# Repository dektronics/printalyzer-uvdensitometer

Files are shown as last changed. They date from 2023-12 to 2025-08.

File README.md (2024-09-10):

# Printalyzer UV/VIS Densitometer

Printalyzer Densitometer Logo

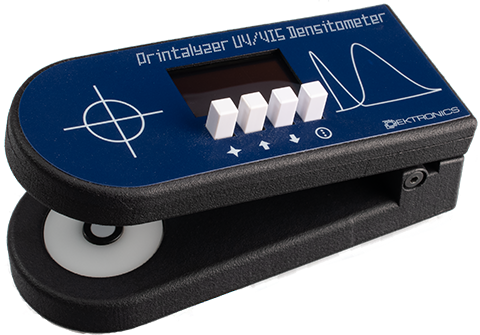
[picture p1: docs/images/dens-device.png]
Printalyzer Densitometer Device


## Introduction

The Printalyzer UV/VIS Densitometer is a project whose goal is the creation of an
affordable reflection and transmission densitometer for photographic darkroom
use.

It differs from the original B&W densitometer product in that it adds a UV
measurement channel for alternative processes needs.

This project will use the B&W [Printalyzer Densitometer](https://github.com/dektronics/printalyzer-densitometer) DPD-100 design as its basis, and will make all efforts to share the same mechanical design and components.

_**This project is currently very much in the R&D stage, and should not be considered complete or functional at this point. It may change substantially as initial prototypes are constructed and tested.**_

## Project Layout

### Hardware
The "hardware" directory contains [KiCad](https://www.kicad.org/) projects
with the complete circuit schematics, bill-of-materials, and
PCB layouts.

### Software
The "software" directory contains all the source code for the bootloader
and firmware that runs on the hardware.

The desktop software to interface with this densitometer from a computer is
maintained in a separate repository, as it contains support for multiple
densitometer devices.

### Enclosure
The "enclosure" directory contains any CAD models and related resources
necessary to physically assemble the device.

## License
Individual directories will contain LICENSE files as needed, with relevant
details. Generally, the hardware will be CC BY-SA and the software will be
BSD 3-Clause. However, external resources may have their own individual license terms.

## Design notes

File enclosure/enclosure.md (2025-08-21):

# Printalyzer UV/VIS Densitometer Enclosure

## Introduction

This directory contains all the assets necessary to produce the physical
enclosures for the Printalyzer Densitometer. This document explains what
component each file represents, and also provides a bill-of-materials
for additional hardware needed for assembly.

The actual assembly instructions are located elsewhere.

## 3D Models

Models designed for 3D printing are provided as both STL and 3MF files,
and are listed without their file extension.

Original CAD files are provided in the native format of the CAD application.

The models that make up the construction of the device must be printed
in a material that is minimally reflective and opaque to both visible and
infrared light.

_**Note: Many of the models for components beyond the main enclosure were
created by deriving from either the main assembly CAD project or related
projects that might include non-distributable models of 3rd party
components. As such, original CAD files may not be provided for everything
listed here.**_

These files are in the `models_3d` subdirectory.

### CAD Projects

* `dens-enclosure.f3z` - Main CAD model for the enclosure, designed in Fusion 360.  
  (_Note: Does not include models of the PCBs or mounting hardware, to avoid
  accidentally redistributing component models that are under restrictive
  license terms._)

### Main Enclosure Components

* `dens-main-housing` - Main housing for the circuit board and major components
* `dens-main-cover` - Top cover for the main housing
* `dens-main-cover-dev` - Alternative top cover with a clearance hole for a debug connector
* `dens-base` - Base housing that contains the transmission LED components
* `dens-base-cover` - Bottom cover for the base housing

### Internal Components

* `filter-stack-holder` - Tray that sits on top of the lens assembly and holds the sensor diffuser
* `filter-stack-lower-ring` - Lower ring that acts as a spacer, aperture, and helps to hold the sensor
  diffuser in place.
* `filter-stack-upper-ring` - Upper ring that sits between the filter stack and the main circuit
  board to act as a light seal. Should be made from an opaque flexible material, such as rubber or foam.
* `sensor-board-cover` - Internal cover for the backside of the circuit board above the sensor elements

### Assembly Jigs

* `jig-dens-main-assembly` - Jig to hold the main housing during assembly
* `jig-dens-base-assembly` - Jig to hold the base, upside down, during assembly
* `jig-display-mounting` - Jig to help align the PCB and OLED display for assembly
* `jig-overlay-mounting` - Jig to help align the main cover and graphic overlay for assembly
* `jig-spring-trimmer-base` - Base portion of a jig to help hold the torsion springs
  in place while trimming them with a rotary tool
* `jig-spring-trimmer-cover` - Cover portion of a jig to help hold the torsion springs
  in place while trimming them with a rotary tool
* `jig-upside-down` - Jig to hold the complete device in an upside-down orientation,
  which is useful for mating the top and bottom halves and for installing the base cover
* `jig-cal-strip-measure` - Jig for holding a calibration reference for measurement,
  when the label markings have not yet been applied

### Calibration Jigs

* `jig-cal-t2120-center` - Jig to repeatably position a Stouffer T2120 step wedge for linearity calibration (center position)
* `jig-cal-t2120-side` - Jig to repeatably position a Stouffer T2120 step wedge for linearity calibration (side position)
* `jig-cal-t5100-full` - Jig to repeatably position s Stouffer T5100 step wedge for measurement or target calibration (measurement spot at the patch center)
* `jig-cal-t5100-labeled` - Jig to repeatably position a Stouffer T5100 step wedge for measurement or target calibration (measurement spot shifted to accommodate a 4x1" label)

## 2D Models

Models designed for laser cutting are provided as DXF files.
They are provided in both single-part and multi-part grid versions.

These files are in the `models_2d` subdirectory.

* `stage-plate-ring.dxf` - The stage plate outer ring. Cut from a white acrylic
  material that is 1.5mm thick.
* `filter-stack-upper-ring.dxf` - Alternative version of the filter stack upper ring model
  from above, to be used if laser cutting from a stock material. Must use a clean, opaque,
  and flexible material that is 1.5mm thick.
* `sensor-board-cover.dxf` - Alternative version of the sensor board cover
  from above. Must be cut from a material that is opaque to visible and
  infrared light and that is approximately 1mm thick. If thicker, then the
  mounting screws in the sensor head area will need to be longer.

## Graphic Overlay

The graphic overlay is a piece of custom cut polycarbonate material
that has printing and a transparent window for the display.
For all device builds so far, it has been ordered from [JRPanel](https://www.jrpanel.com/).
These files are the design artifacts that have been used when placing
that order.

These files are in the `overlay` subdirectory.

* `graphic-overlay-dims.pdf` - CAD drawing showing all the relevant
  dimensions of the overlay
* `graphic-overlay.dxf` - 2D CAD file representing the relevant
  dimensions of the overlay
* `graphic-overlay.svg` - Inkscape design for the overlay, annotated as appropriate.
* `graphic-overlay.pdf` - PDF export of the design, for ease of exchange.

## Product Labels

* 2x1" label, Zebra Z-Xtreme 4000T High-Tack Silver, SKU: 10023174

## Additional Components

### Non-PCB Electronic Components

These are components that are not included in the PCB's bill-of-materials,
but are ordered from the same kinds of vendors and are necessary to assemble
a complete device.

* Button caps (x4)
  * **E-Switch 1SWHT**
  * Mouser PN: 612-1S-WHT
* 1.3" OLED Display Screen
  * **ER-OLED013A1-1W**
  * https://www.buydisplay.com/white-1-3-inch-oled-i2c-arduino-ssd1306-display-module-connector-fpc
* Cable to connect Transmission LED Board to Main Board
  * **JST JUMPER 04SR-3S - 04SR-3S 4"**
  * Manufacturer PN: A04SR04SR30K102A

### Non-Electronic Components

These components are not necessarily sourced from electronics vendors, but
are still necessary for the assembly of the device.

* Sensor head lens
  * Aspherical focusing acrylic plano-convex lens, 5mm diameter
  * Sourced from AliExpress
  * https://www.aliexpress.us/item/3256802937733209.html
* Sensor head aperture
  * M2 Hard Fiber Washer, 2.3mm inside diameter, 5mm outside diameter
  * McMaster-Carr PN: 95225A210
* Sensor head diffuser
  * UV Fused Silica diffuser, 10mm diameter, 1mm thick
  * Sourced from UQG Optics, part number **DUV-1010**
* Transmission light diffuser
  * White flashed opal, 6mm diameter, 2.5mm thick
  * Sourced from UQG Optics as a custom order
* Transmission light diffuser gasket
  * Square-Profile Oil-Resistant Buna-N O-Ring
  * 1.5mm wide, 6mm inside diameter
  * McMaster-Carr PN: 1171N142

## Assembly Hardware

* M2 x 4mm thread forming screws (x2)
  * McMaster-Carr PN: 90380A324
* M2 x 5mm thread forming screws (x2)
  * McMaster-Carr PN: 90380A325
* M2 x 6mm thread forming screws (x4)
  * McMaster-Carr PN: 90380A326
* M2 x 8mm thread forming screws (x4)
  * McMaster-Carr PN: 90380A328
* M2 x 8mm flat head black screws (x4)
  * McMaster-Carr PN: 91698A204
* M3 x 20mm low-profile socket head partially threaded screws (x2)
  * McMaster-Carr PN: 93070A076
* Torsion Spring, 180 deg Right-Hand wound
  * McMaster-Carr PN: 9271K97
  * Gardner Spring PN: GT2814018-MR
* Torsion Spring, 180 deg Left-Hand wound
  * McMaster-Carr PN: 9271K98
  * Gardner Spring PN: GT2814018-ML
* Flanged sleeve bearings for 3mm shaft, 5mm long (x2)
  * McMaster-Carr PN: 2705T112
  * Igus PN: JFM-0304-05
* Rubber bumbers (x4)
  * **3M BUMPER CYLIN 0.315" DIA BLACK**
  * Manufacturer PN: SJ5076
  * Digi-Key PN: 3M156065-ND
* Adhesive wheel weights, 1/4 oz (x6)
  * Available from a variety of vendors
* All-purpose adhesive
  * E6600 QuickHOLD
* UV-Curing adhesives
  * Norland Products NOA 68
  * Norland Products NOA 72
* Foam mounting tape (3/4"x 15ft)
  * **3M VHB 3/4-5-4991**
  * McMaster-Carr PN: 8127A88

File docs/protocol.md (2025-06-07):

USB Control Protocol
====================

The Printalyzer Densitometer presents itself to a host computer as a USB CDC
device, which is essentially a virtual serial port. Through this interface,
it is possible to configure and control all aspects of the device.
This document covers that protocol.

## Data Formats

All command and response lines are terminated by a CRLF (`\r\n`).

### Command Format

Each command is sent in a standardized form:

`<TYPE><CATEGORY> <ACTION>[,<ARGS>]`
* **TYPE** values:
  * `S` - Set (change a value or state)
  * `G` - Get (return a value or state)
  * `I` - Invoke (perform some action on the system)
* **CATEGORY** values:
  * `S` - System (top-level system commands)
  * `M` - Measurement (commands related to density measurements)
  * `C` - Calibration (commands related to device calibration)
  * `D` - Diagnostics (general diagnostic commands)
* **ACTION** values are specific to each category, and documented in the following sections
* **ARGS** values are specific to each action, and not all actions may have them

### Response Format

Command responses typically fit a format that is a mirror of the command that
triggered them, except the `[,<ARGS>]` field is changed to represent
information specific to that particular command response.

The common formats for these response arguments are:
* `OK` - The command completed successfully, with no further information
* `ERR` - The command failed
* `NAK` - The command was either unrecognized or can't be processed in the current system state
* `A,B,C,D` - A comma-separated list of elements
  * Strings in this list may be quoted
  * Floating point values are returned in a little-endian hex encoded format
* A multi-line response as follows:
  ```
  TC ACTION,[[\r\n
  Line 1
  Line 2
  ...
  ]]\r\n  
  ```

### Density Format

Density readings are sent out-of-band whenever a reading is taken on the device,
and are not sent in response to commands. They follow the format of:

`<R/T/U><+/->#.##D`

An example of a density reading would be something like `R+0.20D`, `T+2.85D`, or `U+1.90D`

### Logging Format

Redirected log messages have a unique prefix of `L/`, where "L" is the logging level.
By looking for this pattern, they can be filtered out from the rest of the command
protocol. By default, log messages are not redirected out the USB CDC interface.

Expected log levels include: `A`, `E`, `W`, `I`, `D`, and `V`

## Commands

Note: Commands that could conflict with the local device user interface
may require that the device first be placed into "remote control" mode.
If sent outside of this mode, they may fail with a **NAK**. Commands of
this type are marked below.

Commands that lack a documented response format will return either `OK` or `ERR`.

### System Commands

* `GS V` - Get project name and version
  * Response: `GS V,<Project name>,<Version>`
* `GS B` - Get firmware build information
  * Response: `GS B,<Build date>,<Build describe>,<Checksum>`
* `GS DEV`  - Get device information
  * Response: `GS DEV,<HAL Version>,<MCU Device ID>,<MCU Revision ID>,<SysClock Frequency>`
* `GS RTOS` - Get FreeRTOS information
  * Response: `GS RTOS,<FreeRTOS Version>,<Heap Free>,<Heap Watermark>,<Task Count>`
* `GS UID`  - Get device unique ID
  * Response: `GS UID,<UID>`
* `GS ISEN` - Internal sensor readings
  * Response: `GS ISEN,<VDDA>,<MCU_Temp>,<Sensor_Temp>`
  * Note: Response elements have unit suffixes appended, so it looks like "3300mV,24.5C,22.0C"
* `IS REMOTE,n` - Invoke remote control mode (enable = 1, disable = 0)
  * Response: `IS REMOTE,n`
* `SS DISP,"text"` - Write the provided text to the display ***(remote mode)***
  * Note: Line breaks are sent as the literal text "\n"
    and backslashes are sent as the literal text "\\".
    Double-quote characters inside the string are not supported. ***(remote mode)***
* `SS DISP, n` - Set the display to be enabled or disabled (enable = 1, disable = 0)

### Measurement Commands

* `GM REFL` - Get last VIS reflection measurement
  * Response: `GM REFL,<D>`
* `GM TRAN` - Get last VIS transmission measurement
  * Response: `GM TRAN,<D>`
* `GM UVTR` - Get last UV transmission measurement
  * Response: `GM TRAN,<D>`
* `SM FORMAT,x` - Change measurement output format
  * Possible measurement formats are:
    * `BASIC` - The default format, which just includes the measurement mode
      and density value in a human-readable form, to 2 decimal places
    * `EXT` - Appends the density, zero offset, and gain adjusted basic count
      readings in the hex encoded floating point format
  * Note: The active format will revert to **BASIC** upon disconnect
* `SM UNCAL,x` - Allow measurements without target calibration (0=false, 1=true)
  * Note: This setting will revert to false upon disconnect

### Calibration Commands

* `IC GAIN` - Invoke the sensor gain calibration process ***(remote mode)***
  * This is a long process in which the device must be held closed.
    It will automatically abort if the hinge detect switch is released
    during the process.
  * The result of this process will be updated measurement light and
    sensor gain calibration values.
  * While running, there will be a series of `STATUS` responses followed by
    a single `OK` or `ERR` response.
  * Status is reported via the following responses:
    * `IC GAIN,STATUS,n,m` where n is an enumerated value as follows:
      * 0 = initializing
      * 1 = finding gain measurement brightness (m = gain level)
      * 2 = waiting between measurements
      * 3 = measuring gain level (m = gain being measured)
      * 4 = calibration process failed
      * 5 = calibration process complete
    * `IC GAIN,OK` - Gain calibration process is complete
    * `IC GAIN,ERR` - Gain calibration process has failed
* `GC GAIN` - Get sensor gain calibration values
  * Response: `GC GAIN,<G0>,<G1>,<G2>,<G3>,<G4>,<G5>,<G6>,<G7>,<G8>,<G9>`
  * Note: `<G0..9>` represent gain values, doubling with each increment, from 0.5x to 256x
* `SC GAIN,<G0>,<G1>,<G2>,<G3>,<G4>,<G5>,<G6>,<G7>,<G8>,<G9>` - Set sensor gain calibration values
* `GC VTEMP` - Get VIS sensor temperature calibration values
  * Response: `GC VTEMP,<B0>,<B1>,<B2>`
* `SC VTEMP,<B0>,<B1>,<B2>` - Set VIS sensor temperature calibration values
  * _Note: There is no on-device way to perform temperature calibration.
    It is performed using an externally controlled process that captures
    device measurements while the device is inside a thermal test chamber,
    does a series of calculations, then provides a set of coefficients
    that are loaded onto the device using this command._
* `GC UTEMP` - Get UV sensor temperature calibration values
  * Response: `GC VTEMP,<B0>,<B1>,<B2>`
* `SC UTEMP,<B0>,<B1>,<B2>` - Set UV sensor temperature calibration values
* `GC REFL` - Get VIS reflection density calibration values
  * Response: `GC REFL,<LD>,<LREADING>,<HD>,<HREADING>`
* `SC REFL,<LD>,<LREADING>,<HD>,<HREADING>` - Set VIS reflection density calibration values
  * The reading values are assumed to be in gain adjusted basic counts
* `GC TRAN` - Get VIS transmission density calibration values
  * Response: `GC TRAN,<LD>,<LREADING>,<HD>,<HREADING>`
* `SC TRAN,<LD>,<LREADING>,<HD>,<HREADING>` - Get VIS transmission density calibration values
  * The reading values are assumed to be in gain adjusted basic counts
  * Note: `<HD>` is always zero, and only included here for the sake of consistency
* `GC UVTR` - Get UV transmission density calibration values
  * Response: `GC UVTR,<LD>,<LREADING>,<HD>,<HREADING>`
* `SC UVTR,<LD>,<LREADING>,<HD>,<HREADING>` - Get UV transmission density calibration values
  * The reading values are assumed to be in gain adjusted basic counts
  * Note: `<HD>` is always zero, and only included here for the sake of consistency

### Diagnostic Commands

* `GD DISP` - Get display screenshot
  * Response is XBM data in the multi-line format described above
* `GD LMAX` -> Get maximum light duty cycle value
* `SD LR,nnn` -> Set VIS reflection light duty cycle (nnn/LMAX) ***(remote mode)***
  * Light sources are mutually exclusive. To turn all off, set any to 0.
    To turn on to full brightness, set to LMAX.
* `SD LT,nnn` -> Set VIS transmission light duty cycle (nnn/LMAX) ***(remote mode)***
  * Light sources are mutually exclusive. To turn all off, set any to 0.
    To turn on to full brightness, set to LMAX.
* `SD LTU,nnn` -> Set UV transmission light duty cycle (nnn/LMAX) ***(remote mode)***
  * Light sources are mutually exclusive. To turn all off, set any to 0.
    To turn on to full brightness, set to LMAX.
* `ID S,START` - Invoke sensor start ***(remote mode)***
  * When the sensor task is started via this diagnostic command, there is an
    implicit "Get Reading" command every time a result is available. Thus,
    results are periodically returned as long as the task is running.
  * Result format: `GD S,<DATA>,<GAIN>,<TIME>,<COUNT>`
* `ID S,STOP` - Invoke sensor stop ***(remote mode)***
* `SD S,MODE,<M>` - Set sensor spectrum measurement mode ***(remote mode)***
  * `<M>` - Sensor photodiode configuration
    * `0` - Default configuration
    * `1` - Visual (Photopic) mode
    * `2` - UV-A mode
* `SD S,CFG,g,t,c` - Set sensor gain (n = [0-9]), integration time (t = [0-2047]), and integration count (c = [0-2047]) ***(remote mode)***
* `SD AGCEN,c` - Enable automatic gain control with sample count (c = [0-2047]) ***(remote mode)***
* `SD AGCDIS` - Disable automatic gain control
* `ID READ,<L>,<nnn>,<M>,<G>,<T>,<C>` - Perform controlled sensor target read ***(remote mode)***
  * `<L>` - Measurement light source
    * `0` - Light off
    * `R` - VIS Reflection light, full power
    * `T` - VIS Transmission light, full power
    * `U` - UV Transmission light, full power
  * `<nnn>` - Measurement light duty cycle (nnn/LMAX)
    * 0 is off, LMAX is full brightness
  * `<M>` - Sensor photodiode configuration
    * `0` - Default configuration
    * `1` - Visual (Photopic) mode
    * `2` - UV-A mode
  * `<G>` - Sensor gain (0-9)
  * `<T>` - Sensor integration sample time (0-2047)
  * `<C>` - Sensor integration sample count (0-2047)
  * Result format: `ID READ,<DATA>` (Result is raw sensor counts)
  * _Note: This operation behaves similarly to a real measurement, synchronizing
    read light control to the measurement loop, and averaging across a number
    of readings. Unlike a real measurement it uses preconfigured gain and
    integration settings, rather than automatically adjusting them as part
    of the cycle, and returns raw sensor data. It is intended for use as part of
    device characterization routines where repeatable measurement conditions
    are necessary._
* `ID MEAS,<L>,<nnn>` - Perform normal density measurement read cycle ***(remote mode)***
  * `<L>` - Measurement light and sensor mode
    * `R` - VIS Reflection measurement
    * `T` - VIS Transmission measurement
    * `U` - UV Transmission measurement
  * `<nnn>` - Measurement light duty cycle (nnn/LMAX)
    * 0 is off, LMAX is full brightness
  * Result format: `ID MEAS,<DATA>` (Result is floating-point "Basic counts")
  * _Note: This operation behaves exactly the same as a real measurement,
    including automatic gain selection and repeatable timing. Unlike a
    real measurement, it provides lower-level sensor data instead of a user
    visible density result.
    It is intended for use as part of device characterization routines which
    need an automated way to take measurements without having to hard-code
    sensor parameters._
* `ID WIPE,<UID>,<CKSUM>` - Factory reset of configuration memory ***(remote mode)***
  * `<UIDw2>` is the last 4 bytes of the device UID, in hex format
  * `<CKSUM>` is the 4 byte checksum of the current firmware image, in hex format
  * _Note: After acknowledging this command, the device will perform the wipe
    and then reset itself. The connection will be lost in the process._
* `SD LOG,U` -> Set logging output to USB CDC device
* `SD LOG,D` -> Set logging output to debug port UART (default)

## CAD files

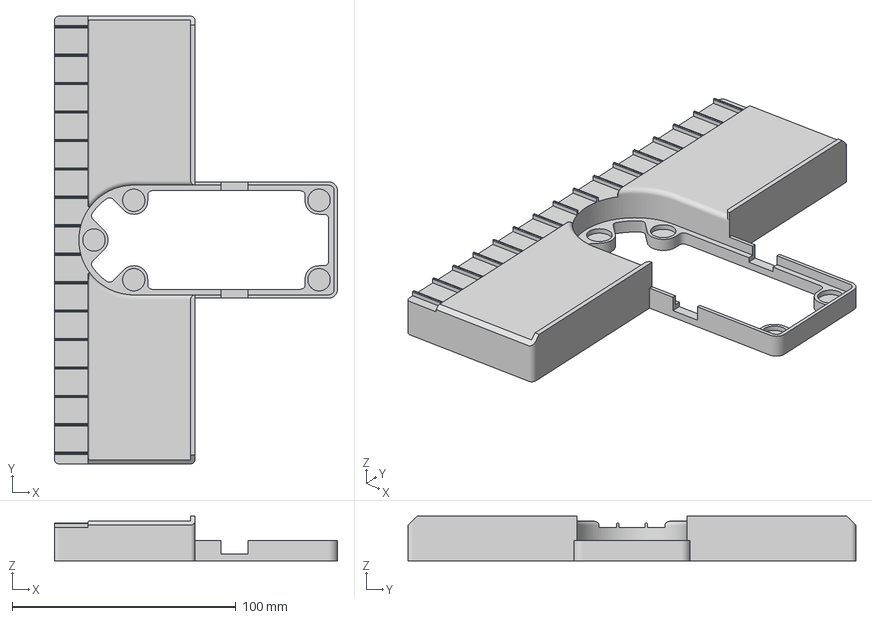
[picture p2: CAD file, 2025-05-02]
enclosure/models_3d/jig-cal-t5100-full.3mf
126.4 x 200.0 x 20.0 mm

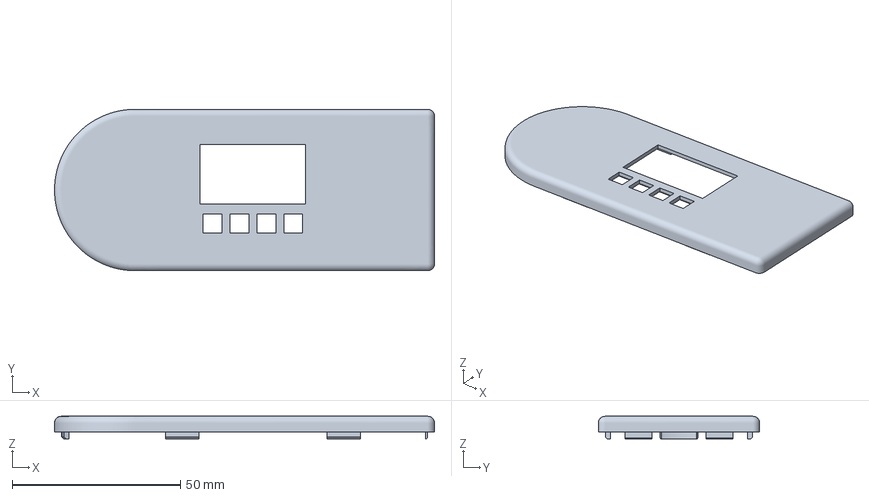
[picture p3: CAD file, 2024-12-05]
enclosure/models_3d/dens-main-cover.3mf
113.0 x 48.0 x 6.70 mm

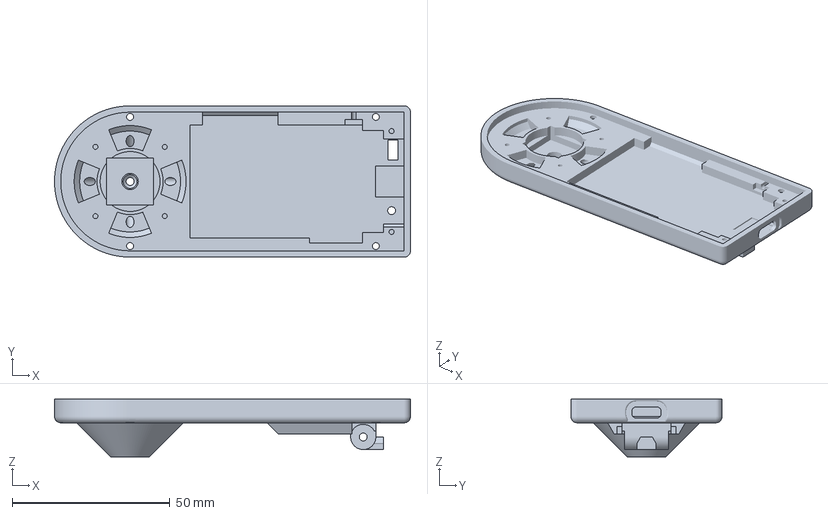
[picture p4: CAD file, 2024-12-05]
enclosure/models_3d/dens-main-housing.3mf
113.0 x 48.0 x 18.3 mm

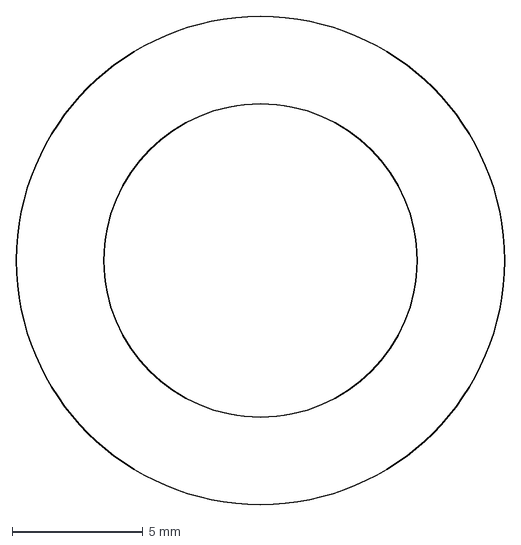
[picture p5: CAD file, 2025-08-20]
enclosure/models_2d/filter-stack-upper-ring.dxf
18.7 x 18.7 mm

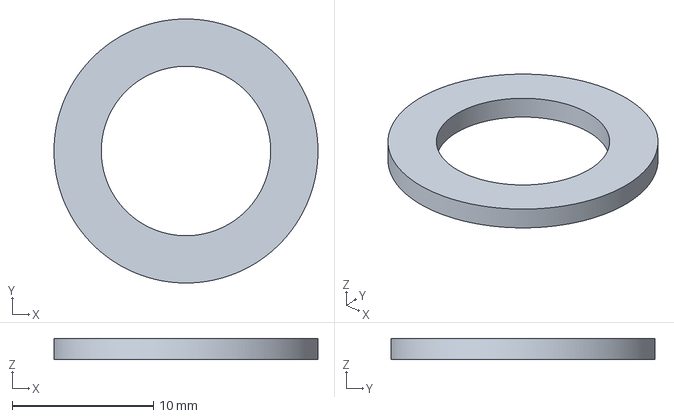
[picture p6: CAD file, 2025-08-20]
enclosure/models_3d/filter-stack-upper-ring.3mf
18.7 x 18.7 x 1.50 mm

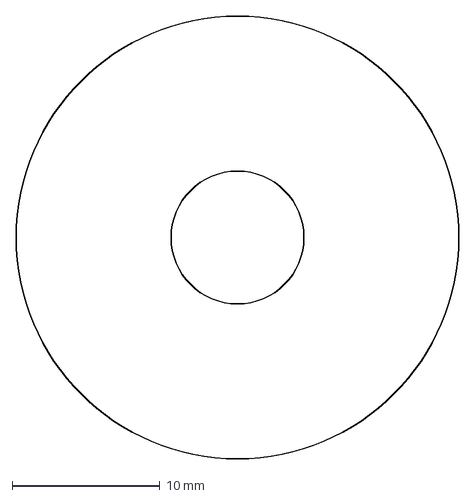
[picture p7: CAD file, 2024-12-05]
enclosure/models_2d/stage-plate-ring.dxf
30.0 x 30.0 mm

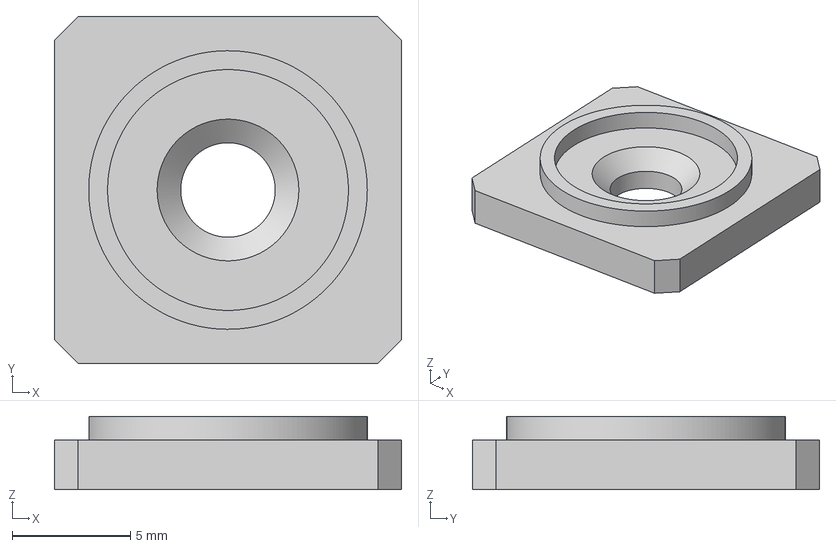
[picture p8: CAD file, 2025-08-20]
enclosure/models_3d/filter-stack-holder.3mf
14.7 x 14.7 x 3.10 mm

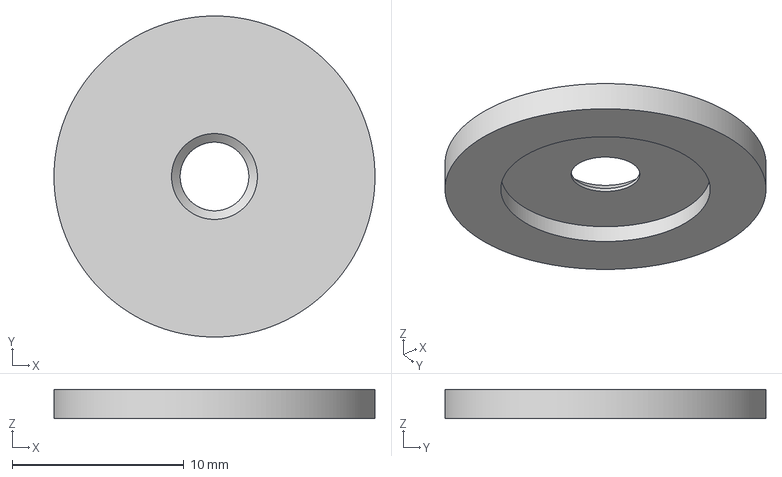
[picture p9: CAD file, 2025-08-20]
enclosure/models_3d/filter-stack-lower-ring.3mf
18.7 x 18.7 x 1.70 mm

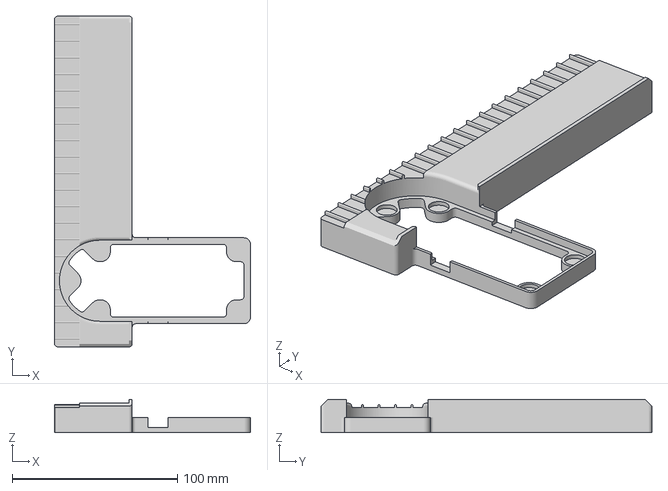
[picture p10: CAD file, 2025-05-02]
enclosure/models_3d/jig-cal-t2120-side.3mf
118.5 x 200.0 x 20.0 mm

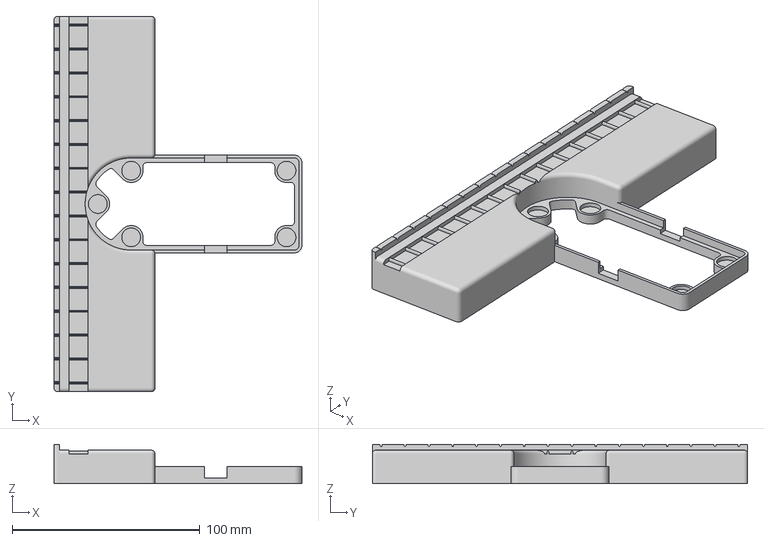
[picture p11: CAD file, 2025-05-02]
enclosure/models_3d/jig-cal-t5100-labeled.3mf
132.1 x 200.0 x 20.8 mm

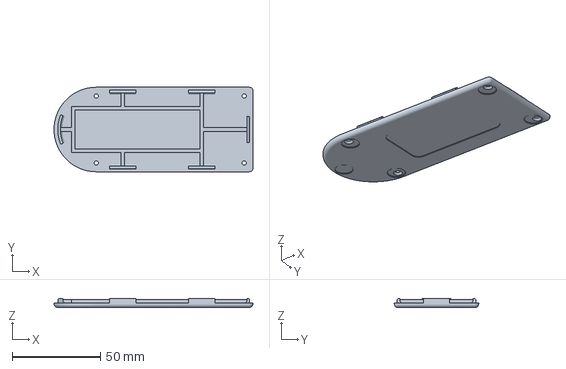
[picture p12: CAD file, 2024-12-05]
enclosure/models_3d/dens-base-cover.3mf
113.0 x 48.0 x 5.00 mm

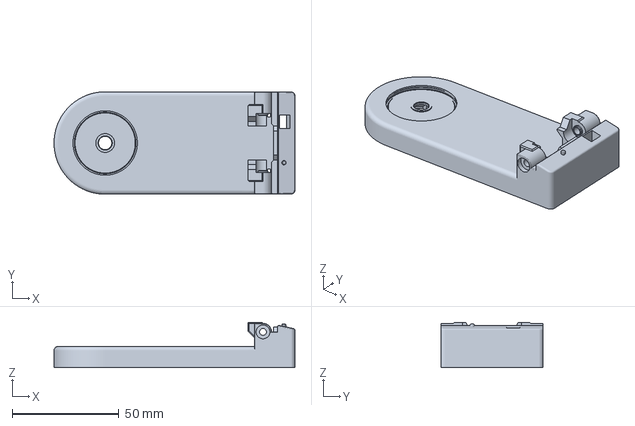
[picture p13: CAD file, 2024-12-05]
enclosure/models_3d/dens-base.3mf
113.0 x 48.0 x 21.3 mm

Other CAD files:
enclosure/models_3d/jig-cal-t2120-center.3mf
enclosure/models_3d/dens-base-cover.stl
enclosure/models_3d/dens-base.stl
enclosure/models_3d/dens-enclosure.f3z
enclosure/models_3d/dens-main-cover.stl
enclosure/models_3d/dens-main-housing.stl
enclosure/models_3d/filter-stack-holder.stl
enclosure/models_3d/filter-stack-lower-ring.stl
enclosure/models_3d/filter-stack-upper-ring.stl
enclosure/models_3d/jig-cal-t2120-center.stl
enclosure/models_3d/jig-cal-t2120-side.stl
enclosure/models_3d/jig-cal-t5100-full.stl
enclosure/models_3d/jig-cal-t5100-labeled.stl

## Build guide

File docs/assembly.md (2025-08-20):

# Printalyzer UV/VIS Densitometer Assembly

This document describes the process of assembling a complete
Printalyzer UV/VIS Densitometer from its major components. It assumes that the
assembly of printed circuit boards, along with any soldered-in components,
has been performed prior to following this document. The steps laid out
herein are written with the assumption that they are performed in sequential
order. In practice, independent steps may be reordered as appropriate for
batch assembly.

The majority of the bill-of-materials for this process is contained within
the [enclosure](../enclosure/enclosure.md) document. Please refer there for
detailed descriptions and part numbers for any components listed here.

## Main Board Assembly

### Components

* Main Board (assembled PCB)
* Button caps (x4)
* OLED Display Screen
* Foam mounting tape

### Tools

* Display mounting jig (`jig-display-mounting`)
* Knife or scissors

### Steps

* Mount the display
  * Cut a 3cm piece of mounting tape, and affix to the main board over the
    rectangular silkscreen markings that represent the center of a display
    component.
  * Insert the display screen, face-down, into the recessed rectangular area
    on the display mounting jig. Do not remove the protective cover.
  * Remove the outer film from the mounting tape, exposing the rest of the
    adhesive.
  * Carefully lower the main board onto the dowel pins sticking up from the
    mounting jig, until the display is affixed to the tape.
  * Remove the main board from the jig, and carefully apply additional
    pressure with your fingers to ensure everything is securely in place.
  * Insert the display flat flex cable into the socket on the opposing side
    of the main board, and lock it in place with the socket tabs.
* Press-fit the button caps onto the tactile switches on the main board.

## Base

### Components

* Base housing (`dens-base`)
* Stage Plate Outer Ring (`stage-plate-rings`)
* Transmission light diffuser (6x2.5mm flashed opal)
* Transmission light diffuser gasket (1.5mm square profile, 6mm ID, o-ring)
* Transmission Board (assembled PCB)
* Adhesive wheel weights (x6)
* Jumper cable assembly
* M2 x 4mm thread forming screws (x2)

### Tools

 * Base assembly jig (`jig-dens-base-assembly`)
 * Diffuser positioning jig
 * Scrap paper
 * Toothpick
 * Screwdriver
 * Knife
 * All-purpose adhesive (E6600)
 * Norland Products NOA 68 UV curing adhesive
 * UV curing light
 * Cyanoacrylate glue

### Steps

* Affix adhesive weights
  * Use a knife on a hard surface to cut the wheel weights into four distinct
    pieces; two singles and two pairs.
  * Remove the backing paper and press the pieces into the underside of the base.
    The singles go in recesses just behind the board mounting area, and the
    pairs go in larger recesses further back.
  * Squirt beads of all-purpose adhesive into all the interior crevices surrounding
    the weights.
  * Allow to dry for 24 hours.
* Install the transmission light diffuser
  * Place the o-ring gasket into the center of the diffuser positioning jig.
  * Place the flashed opal diffuser, white-side-down, into the middle of the o-ring.
    Both pieces should be flush on the bottom, with the diffuser sticking out a bit on the top.
  * Squirt a blob of NOA 68 adhesive onto a piece of scrap paper.
  * Use a toothpick to carefully apply this adhesive around the surface of the o-ring
    and the crevice where the diffuser and o-ring meet, being careful to not get any onto the
    flat surface of the diffuser. (This is most easily done under a stereo inspection microscope.)
  * Place the base, upside-down, on top of the diffuser positioning jig, being careful to hold it
    centered and level with respect to the hole.
  * When you are certain that everything is flat, level, and positioned correctly,
    use the UV curing light to cure the adhesive.
* Install the stage plate outer ring
  * Squirt a bead of cyanoacrylate glue liquid around the stage plate outer
    ring recess in the base housing. Use a minimal amount, preferably in a
    circle around the midpoint.
  * Insert the stage plate outer ring, and press down firmly.
  * Let the piece sit and allow the glue to dry.
* Place the base housing upside-down in the base assembly jig.
* Install transmission board
  * Place the board into its spot, and secure with screws.
  * Attach the cable assembly to the board connector.
  * Loop the cable if necessary, for length.
  * Feed the cable out through the cable hole at the rear of the base.

## Base Cover

### Components

* Base cover (`dens-base-cover`)
* Product label
* Rubber bumbers (x4)
* M2 x 8mm flat head black screws (x4)

### Tools

* Base assembly jig (`jig-dens-base-assembly`)
* Screwdriver

### Steps

* Place the Base housing sub-assembly upside-down in the base assembly jig.
* Place cover over the Base housing sub-assembly, and secure with screws
* Apply rubber bumpers in the indents over the screws
* Affix the product label to its indent (can leave this step to the very end)

## Main Housing

### Components

* Main Housing (`dens-main`)
* Sensor head lens
* Sensor head aperture washer
* Sensor head diffuser
* Diffuser holder (`filter-stack-holder`)
* Diffuser lower ring (`filter-stack-lower-ring`)
* Diffuser upper ring (`filter-stack-upper-ring`)
* Sensor Board Cover (`sensor-board-cover`)
* Main Board Assembly
* M2 x 6mm thread forming screws (x4)
* M2 x 5mm thread forming screws (x2)

### Tools

* Main housing assembly jig (`jig-dens-main-assembly`)
* Screwdriver
* Scissors or rotary trimmer
* Microfiber cloth
* Norland Products NOA 72 UV curing adhesive
* UV curing light

### Steps

* Place the Main Housing into the Main housing assembly jig.
* Install the sensor head lens
  * Insert the sensor head lens into the sensor head aperture hole, and make sure
    it is pressed all the way down.
    * The lens is installed with the more convex side facing down
    * Be careful to use non-marking tools and keep the area clean
  * Insert the sensor head aperture washer on top of the lens
  * Carefully apply the NOA 72 adhesive around the perimeter of the lens and washer hole
    * This adhesive has a very thin consistency, so care must be taken when applying it.
    * Best results involve the use of a very fine tip on a syringe, waiting for the fluid
      to stop dribbling, and then using mostly capillary action for the fluid to seep from
      the tip into the perimeter of the hole on the device.
  * When you are certain that everything is level and centered correctly,
    use the UV curing light to cure the adhesive.
  * To ensure consistent and complete curing, it may be advisable to shine the curing light
    from both sides of the lens.
* Install the sensor diffuser/filter stack
  * Insert the diffuser holder
  * Insert the sensor head diffuser, matte side up, into the holder
  * Insert the diffuser lower ring
  * Insert the diffuser upper ring
* Place the Main Board Assembly into the housing
* Place the Sensor Board Cover on top of the Main Board Assembly.
* Secure with screws the board with screws
  * 6mm long screws go on the side with the sensor head
  * 5mm long screws go on the side with the connectors

## Main Cover

### Components

* Main Cover (`main-cover`)
* Graphic Overlay
* Main Housing Assembly
* M2 x 8mm thread forming screws (x4)

### Tools

* Overlay mounting jig (`jig-overlay-mounting`)
* Screwdriver

### Steps

* If the protective cover over the display window on the graphic overlay is
  encroaching on the button holes, then move it as necessary.
* Place the graphic overlay face-down into the jig
* Carefully remove the backing material from the graphic overlay.
* Align and place the main cover, face down, onto the overlay.
* Remove the main cover, and press on a hard surface to make
  sure the overlay is well adhered.
* Remove the protective cover from the mounted display, which is on
  the main board which is installed within the main housing assembly.
* Place the main cover onto the main housing assembly,
  and secure with screws

_Note: The display window cover on the outer surface of the graphic overlay
should probably be left on through shipping, and removed by the end user._

## Final Assembly

### Components

* Main Body Assembly (Main Body + Main Body Cover)
* Base Assembly (Base + Base Cover)
* RH Torsion Spring
* LH Torsion Spring
* Flange sleeve bearings (x2)
* M3 x 20mm low-profile socket head partially threaded screws (x2)

### Tools

* Spring trimmer jig (`jig-spring-trimmer-base` and `jig-spring-trimmer-cover`)
* Rotary tool with cut-off disc
* Screwdriver

### Steps

* Insert springs into the trimmer jig, and cut ~12mm off the bottom end of
  each one using a rotary tool.
* Take trimmed springs, and insert them into the base assembly hinge area
* Insert the flange sleeve bearings onto the inside-facing spring hole,
  and insert the hinge screws from the outside to hold them in place.
* Connect the transmission LED cable to the Main Body Assembly.
* Carefully install the main body assembly onto the spring tines
  and hinge screw/flange assembly.
* Tighten the hinge screws, alternating, to keep centered alignment.

## Post-Assembly

These steps are just a rough outline of the final part of the process, and
will be further refined once the device is in production.

* Install the bootloader, either pre-loading prior to assembly or via
  USB DFU after assembly.
* Install the firmware, either pre-loading prior to assembly or via
  USB DFU/UF2 after assembly.
* Load the "factory" sensor slope calibration data.
* Run the sensor gain calibration routine.
* Calibrate reflection and transmission modes against references
  to be included with the package.

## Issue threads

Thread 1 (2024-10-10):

Fix orientation of ESD321 TVS diodes on the main board

dkonigsberg, 2024-10-10:
Nearly all TVS diodes I've ever used are documented such that pin 1 is the cathode and marked on the package.

Apparently the ESD321DYAR (but **not** the ESD321DPYR) is a special exception to this.  On the ESD321DYAR, pin 1 is still marked, but the cathode is actually on pin 2.

This is briefly mentioned in the [datasheet](https://www.ti.com/lit/ds/symlink/esd321.pdf), on page 3, in a way that's very easy to miss.

It also confused someone enough to result in a [TI forum thread](https://e2e.ti.com/support/interface-group/interface/f/interface-forum/1410599/esd321-pin1-position).

Fixing this on the EDA side likely involves some footprint changes, however as far as the actual PCB is concerned, it is little more than a positioning data and silkscreen update.

This issue is easy to rework on currently affected Rev C prototypes, and can be avoided through assembly instructions on future Rev C prototypes.

Due to the nature of the fix, it shouldn't be necessary to create an actual Rev D to resolve this.  A second issue of Rev C should be good enough, since none of the changes are electrical.

Closed 2024-10-24.

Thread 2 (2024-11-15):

Remove VSYNC crystal reference from the device

dkonigsberg, 2024-11-15:
The current design (Rev C) uses a crystal oscillator and divider to produce a stable reference signal which is routed to the TSL2585's VSYNC pin.  This signal is then used to calibrate the internal oscillator of the sensor.

Doing this does make the timing a little more consistent from device-to-device, however that does not actually matter.  Devices are individually calibrated, so only timing consistency within the same device is important.

In testing, it was shown that oscillator calibration results vary from cycle to cycle, probably because the TSL2585 is only trying to trigger off a single pulse of the reference signal.  This ends up causing more variation from calibration to calibration than there should be.

This effect was most visible during recent tests in a thermal chamber:
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
These graphs show temperature along the X axis, and logarithmic change in sensor reading along the Y axis.  In these graphs, line 1 is with an oscillator calibration before each measurement, and line 2 is without.  Its quite obvious that the data is much cleaner when no oscillator calibration is attempted.

Furthermore, because there are plans to do temperature correction of device readings anyways, this extra step offers little benefit.

dkonigsberg, 2024-11-22:
As part of this change, it may make sense to route VSYNC to the microcontroller.  There could be uses for this, such as an alternative way of kicking off measurement cycles.  Those approaches may or may not actually be used, but having the capability never hurts.

Closed 2024-11-22.

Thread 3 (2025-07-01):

Add on-device display of temperature calibration coefficients

dkonigsberg, 2025-07-01:
This is the one set of numbers used for device calibration that is not visible on-device.  It should be added, simply to provide a way of knowing that the values have been set without needing to use the desktop software.

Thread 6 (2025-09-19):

Fix design errors in the enclosure base cover

dkonigsberg, 2025-09-19:
During assembly, a few issues were spotted with the base cover piece of the enclosure.  These need to be addressed in the model, committed back to the project, and then the part needs to be re-manufactured.

The main issues are:

- The tabs on the inside of the cover are too thick and/or too far apart, preventing a good fit with the base.
- There should be a little more vertical clearance in the area directly below the transmission LED board mounting screws.

Closed 2025-09-24.

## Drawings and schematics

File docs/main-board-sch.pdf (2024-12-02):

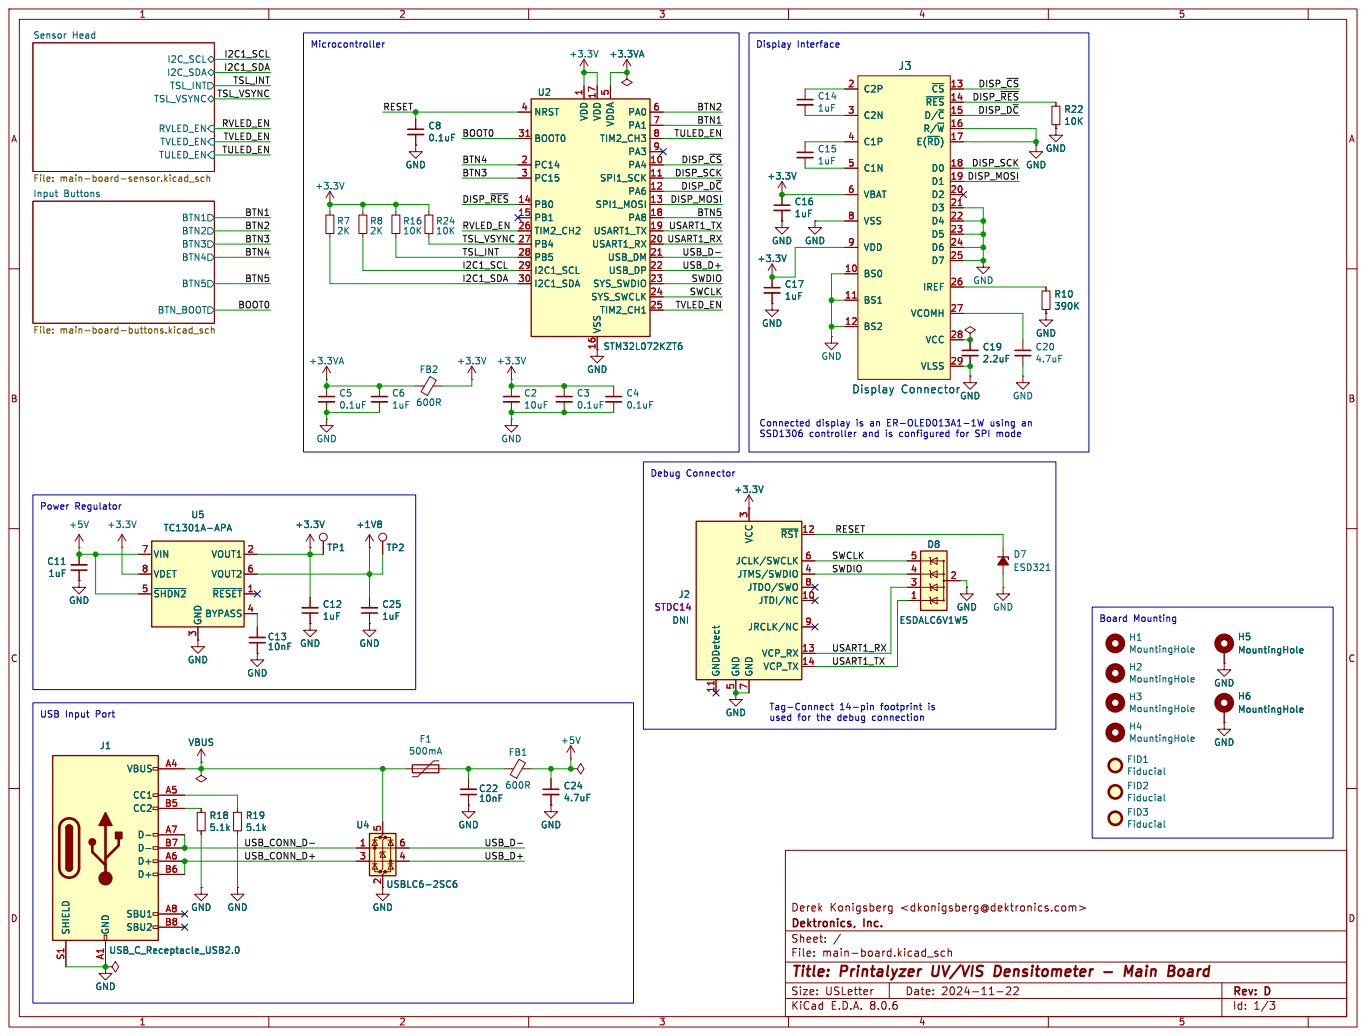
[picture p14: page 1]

IREF 26 VCOMH 27 VCC 28 VLSS 29 C2N 3 C1P 4 C1N 5 VBAT 6 VSS 8 VDD 9 C16

Input Buttons File: main-board-buttons.kicad_sch

3 BYPASS 4 ~{SHDN2} 5 VOUT2 6 VIN 7 VDET 8 U5 TC1301A-APA C3

Id: 1/3 Title: Printalyzer UV/VIS Densitometer - Main Board

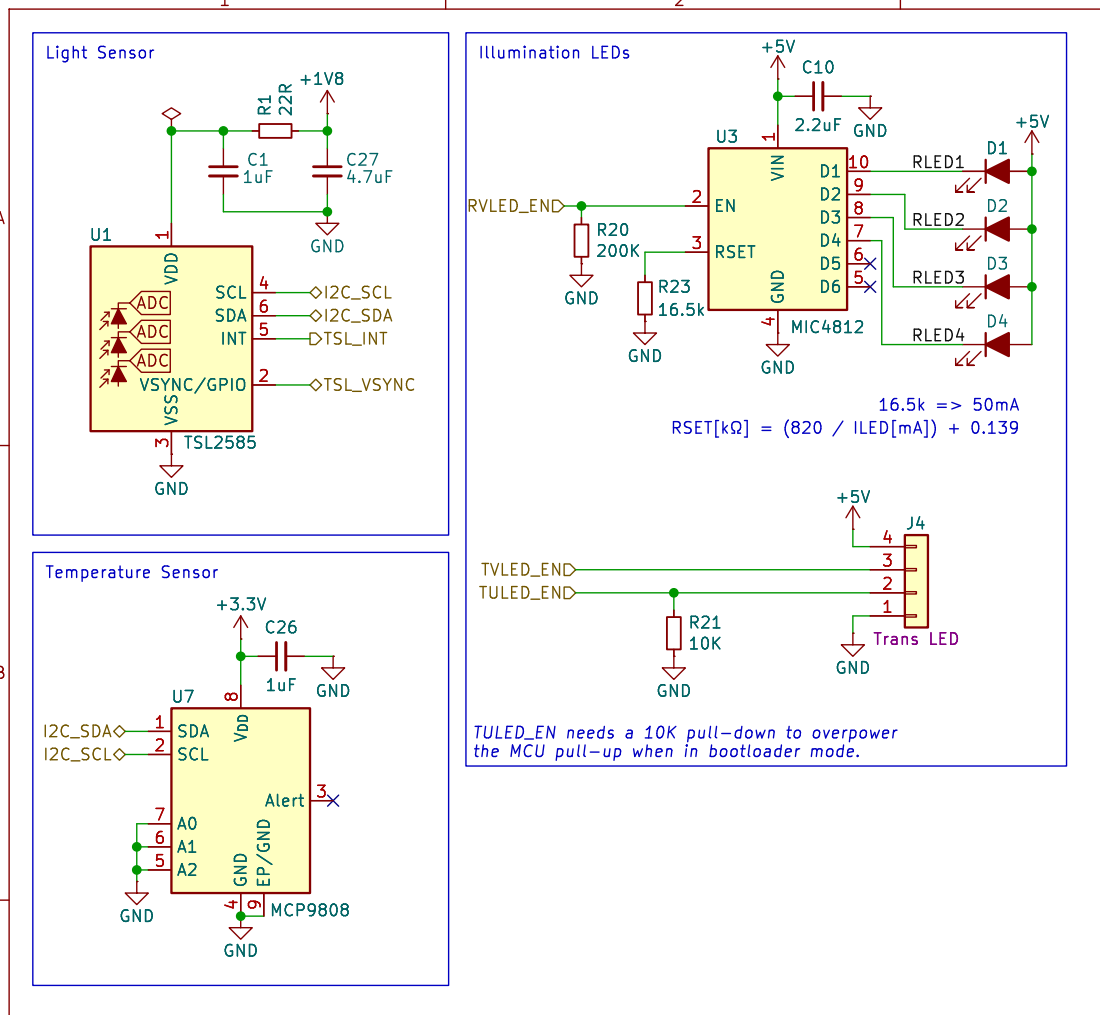
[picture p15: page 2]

Id: 2/3 Title: Printalyzer UV/VIS Densitometer - Main Board

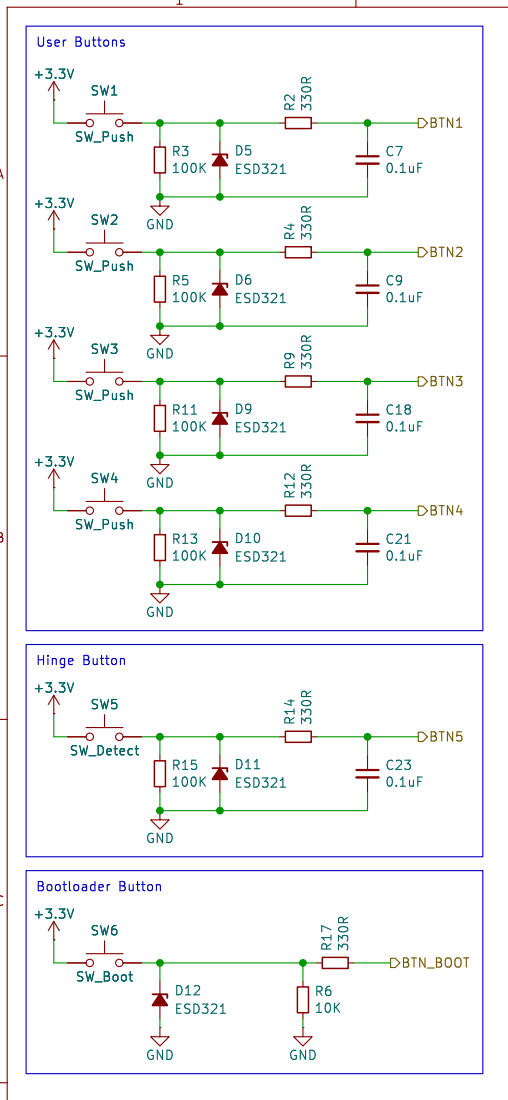
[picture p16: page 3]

Id: 3/3 Title: Printalyzer UV/VIS Densitometer - Main Board

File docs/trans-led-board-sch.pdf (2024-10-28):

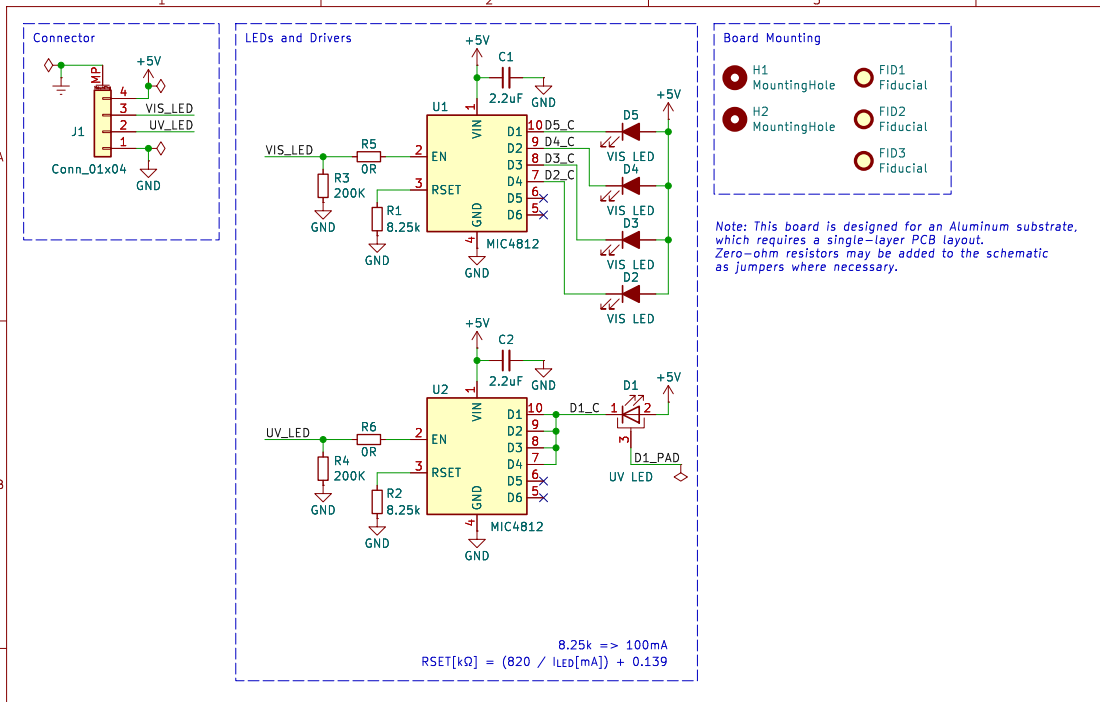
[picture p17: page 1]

3 D1 UV LED GND GND

D4 VIS LED GND GND

Id: 1/1 Title: Printalyzer UV/VIS Densitometer - Transmission LED Board

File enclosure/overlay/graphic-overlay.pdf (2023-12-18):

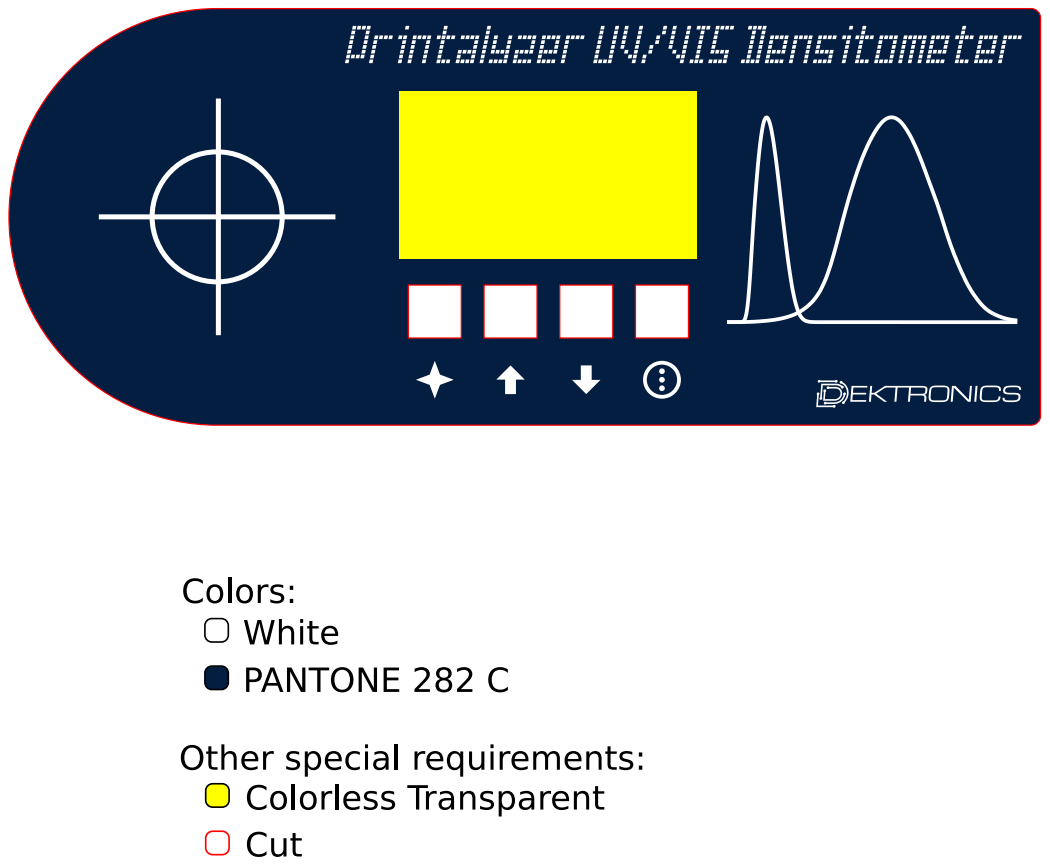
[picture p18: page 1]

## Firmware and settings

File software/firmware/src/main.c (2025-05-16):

#include "main.h"
#include "stm32l0xx_hal.h"

#ifdef USE_SEGGER_RTT
#include "SEGGER_RTT.h"
#endif

#define LOG_TAG "main"
#include <elog.h>

#include <printf.h>
#include <cmsis_os.h>
#include <machine/endian.h>

#include "board_config.h"
#include "keypad.h"
#include "sensor.h"
#include "display.h"
#include "light.h"
#include "adc_handler.h"
#include "task_main.h"
#include "task_sensor.h"
#include "app_descriptor.h"
#include "state_suspend.h"
#include "util.h"

#ifdef HAL_IWDG_MODULE_ENABLED
IWDG_HandleTypeDef hiwdg;
#endif
CRC_HandleTypeDef hcrc;
RTC_HandleTypeDef hrtc;
ADC_HandleTypeDef hadc;
DMA_HandleTypeDef hdma_adc;
I2C_HandleTypeDef hi2c1;
SPI_HandleTypeDef hspi1;
TIM_HandleTypeDef htim2;
#ifndef USE_SEGGER_RTT
UART_HandleTypeDef huart1;
#endif

static uint32_t startup_bkp0r = 0;

static void read_startup_flags(void);
static void iwdg_init(void);
static void rtc_init(void);
#ifndef USE_SEGGER_RTT
static void usart1_uart_init(void);
#endif
static void logger_init(void);
static void gpio_init(void);
static void i2c1_init(void);
static void tim2_init(void);
static void spi1_init(void);
static void crc_init(void);
static void dma_init(void);
static void adc_init(void);
static void usb_init(void);
static void startup_log_messages(void);

void usb_device_task(void *argument);
void cdc_task_func(void *argument);

void error_handler(void);
void HAL_TIM_MspPostInit(TIM_HandleTypeDef *htim);

void system_clock_config(void)
{
    RCC_OscInitTypeDef RCC_OscInitStruct = {0};
    RCC_ClkInitTypeDef RCC_ClkInitStruct = {0};
    RCC_PeriphCLKInitTypeDef PeriphClkInit = {0};

    /* Configure the main internal regulator output voltage */
    __HAL_PWR_VOLTAGESCALING_CONFIG(PWR_REGULATOR_VOLTAGE_SCALE1);

    /*
     * Initialize the RCC Oscillators according to the specified parameters
     * in the RCC_OscInitTypeDef structure.
     */
    RCC_OscInitStruct.OscillatorType = RCC_OSCILLATORTYPE_HSI | RCC_OSCILLATORTYPE_LSI
        | RCC_OSCILLATORTYPE_HSI48;
    RCC_OscInitStruct.HSIState = RCC_HSI_ON;
    RCC_OscInitStruct.HSICalibrationValue = RCC_HSICALIBRATION_DEFAULT;
    RCC_OscInitStruct.LSIState = RCC_LSI_ON;
    RCC_OscInitStruct.HSI48State = RCC_HSI48_ON;
    RCC_OscInitStruct.PLL.PLLState = RCC_PLL_ON;
    RCC_OscInitStruct.PLL.PLLSource = RCC_PLLSOURCE_HSI;
    RCC_OscInitStruct.PLL.PLLMUL = RCC_PLLMUL_6;
    RCC_OscInitStruct.PLL.PLLDIV = RCC_PLLDIV_3;
    if (HAL_RCC_OscConfig(&RCC_OscInitStruct) != HAL_OK) {
        error_handler();
    }

    /* Initialize the CPU, AHB and APB buses clocks */
    RCC_ClkInitStruct.ClockType = RCC_CLOCKTYPE_HCLK | RCC_CLOCKTYPE_SYSCLK
        | RCC_CLOCKTYPE_PCLK1 | RCC_CLOCKTYPE_PCLK2;
    RCC_ClkInitStruct.SYSCLKSource = RCC_SYSCLKSOURCE_PLLCLK;
    RCC_ClkInitStruct.AHBCLKDivider = RCC_SYSCLK_DIV1;
    RCC_ClkInitStruct.APB1CLKDivider = RCC_HCLK_DIV1;
    RCC_ClkInitStruct.APB2CLKDivider = RCC_HCLK_DIV1;
    if (HAL_RCC_ClockConfig(&RCC_ClkInitStruct, FLASH_LATENCY_1) != HAL_OK) {
        error_handler();
    }

    PeriphClkInit.PeriphClockSelection = RCC_PERIPHCLK_USART1 | RCC_PERIPHCLK_I2C1
        | RCC_PERIPHCLK_RTC | RCC_PERIPHCLK_USB;
    PeriphClkInit.Usart1ClockSelection = RCC_USART1CLKSOURCE_PCLK2;
    PeriphClkInit.I2c1ClockSelection = RCC_I2C1CLKSOURCE_PCLK1;
    PeriphClkInit.RTCClockSelection = RCC_RTCCLKSOURCE_LSI;
    PeriphClkInit.UsbClockSelection = RCC_USBCLKSOURCE_HSI48;
    if (HAL_RCCEx_PeriphCLKConfig(&PeriphClkInit) != HAL_OK) {
        error_handler();
    }
}

void read_startup_flags(void)
{
    /*
     * Startup flags are stored in the RTC backup domain registers.
     * Since the backup domain is configured as part of the system
     * clock configuration that occurs prior to this function,
     * it should be left alone here.
     */

    startup_bkp0r = RTC->BKP0R;
    RTC->BKP0R = 0;

    if (startup_bkp0r == 0) {
        startup_bkp0r = RCC->CSR & 0xFF000000UL;
    }
}

void iwdg_init(void)
{
#ifdef HAL_IWDG_MODULE_ENABLED
    hiwdg.Instance = IWDG;
    hiwdg.Init.Prescaler = IWDG_PRESCALER_4;
    hiwdg.Init.Window = 4095;
    hiwdg.Init.Reload = 4095;
    if (HAL_IWDG_Init(&hiwdg) != HAL_OK) {
        error_handler();
    }
    __HAL_RCC_DBGMCU_CLK_ENABLE();
    __HAL_DBGMCU_FREEZE_IWDG();
#endif
}

void rtc_init(void)
{
    /* Initialize RTC Only */
    hrtc.Instance = RTC;
    hrtc.Init.HourFormat = RTC_HOURFORMAT_24;
    hrtc.Init.AsynchPrediv = 127;
    hrtc.Init.SynchPrediv = 255;
    hrtc.Init.OutPut = RTC_OUTPUT_DISABLE;
    hrtc.Init.OutPutRemap = RTC_OUTPUT_REMAP_NONE;
    hrtc.Init.OutPutPolarity = RTC_OUTPUT_POLARITY_HIGH;
    hrtc.Init.OutPutType = RTC_OUTPUT_TYPE_OPENDRAIN;
    if (HAL_RTC_Init(&hrtc) != HAL_OK) {
        error_handler();
    }
}

#ifndef USE_SEGGER_RTT
void usart1_uart_init(void)
{
    huart1.Instance = USART1;
    huart1.Init.BaudRate = 115200;
    huart1.Init.WordLength = UART_WORDLENGTH_8B;
    huart1.Init.StopBits = UART_STOPBITS_1;
    huart1.Init.Parity = UART_PARITY_NONE;
    huart1.Init.Mode = UART_MODE_TX_RX;
    huart1.Init.HwFlowCtl = UART_HWCONTROL_NONE;
    huart1.Init.OverSampling = UART_OVERSAMPLING_16;
    huart1.Init.OneBitSampling = UART_ONE_BIT_SAMPLE_DISABLE;
    huart1.AdvancedInit.AdvFeatureInit = UART_ADVFEATURE_NO_INIT;
    if (HAL_UART_Init(&huart1) != HAL_OK) {
        error_handler();
    }
}
#endif

void logger_init(void)
{
    /* Initialize EasyLogger */
    elog_init();

    /* Set log format */
    elog_set_fmt(ELOG_LVL_ASSERT, ELOG_FMT_ALL);
    elog_set_fmt(ELOG_LVL_ERROR, ELOG_FMT_LVL | ELOG_FMT_TAG | ELOG_FMT_TIME | ELOG_FMT_T_INFO);
    elog_set_fmt(ELOG_LVL_WARN, ELOG_FMT_LVL | ELOG_FMT_TAG | ELOG_FMT_TIME | ELOG_FMT_T_INFO);
    elog_set_fmt(ELOG_LVL_INFO, ELOG_FMT_LVL | ELOG_FMT_TAG | ELOG_FMT_TIME | ELOG_FMT_T_INFO);
    elog_set_fmt(ELOG_LVL_DEBUG, ELOG_FMT_LVL | ELOG_FMT_TAG | ELOG_FMT_TIME | ELOG_FMT_T_INFO);
    elog_set_fmt(ELOG_LVL_VERBOSE, ELOG_FMT_ALL & ~(ELOG_FMT_FUNC | ELOG_FMT_T_INFO | ELOG_FMT_P_INFO));
    elog_set_text_color_enabled(true);

    /* Start EasyLogger */
    elog_start();
}

void gpio_button_config(void)
{
    GPIO_InitTypeDef GPIO_InitStruct = {0};

    /* Configure GPIO pins: BTN4_Pin BTN3_Pin */
    GPIO_InitStruct.Pin = BTN4_Pin | BTN3_Pin;
    GPIO_InitStruct.Mode = GPIO_MODE_IT_RISING_FALLING;
    GPIO_InitStruct.Pull = GPIO_NOPULL;
    HAL_GPIO_Init(GPIOC, &GPIO_InitStruct);

    /* Configure GPIO pins: BTN2_Pin BTN1_Pin BTN5_Pin */
    GPIO_InitStruct.Pin = BTN2_Pin | BTN1_Pin | BTN5_Pin;
    GPIO_InitStruct.Mode = GPIO_MODE_IT_RISING_FALLING;
    GPIO_InitStruct.Pull = GPIO_NOPULL;
    HAL_GPIO_Init(GPIOA, &GPIO_InitStruct);
}

void gpio_button_unconfig(void)
{
    GPIO_InitTypeDef GPIO_InitStruct = {0};

    /* Configure GPIO pins: BTN4_Pin BTN3_Pin */
    GPIO_InitStruct.Pin = BTN4_Pin | BTN3_Pin;
    GPIO_InitStruct.Mode = GPIO_MODE_ANALOG;
    HAL_GPIO_Init(GPIOC, &GPIO_InitStruct);

    /* Configure GPIO pins: BTN2_Pin BTN1_Pin BTN5_Pin */
    GPIO_InitStruct.Pin = BTN2_Pin | BTN1_Pin | BTN5_Pin;
    GPIO_InitStruct.Mode = GPIO_MODE_ANALOG;
    HAL_GPIO_Init(GPIOA, &GPIO_InitStruct);
}

void gpio_init(void)
{
    GPIO_InitTypeDef GPIO_InitStruct = {0};

    /* GPIO Ports Clock Enable */
    __HAL_RCC_GPIOC_CLK_ENABLE();
    __HAL_RCC_GPIOA_CLK_ENABLE();
    __HAL_RCC_GPIOB_CLK_ENABLE();

    /* Configure default GPIO pin output levels for the display */
    HAL_GPIO_WritePin(DISP_CS_GPIO_Port, DISP_CS_Pin, GPIO_PIN_SET);
    HAL_GPIO_WritePin(DISP_DC_GPIO_Port, DISP_DC_Pin, GPIO_PIN_RESET);
    HAL_GPIO_WritePin(DISP_RES_GPIO_Port, DISP_RES_Pin, GPIO_PIN_RESET);

    /* Configure default GPIO pin output level for the sensor VSYNC pin */
    HAL_GPIO_WritePin(SENSOR_VSYNC_GPIO_Port, SENSOR_VSYNC_Pin, GPIO_PIN_SET);

    /* Configure GPIO pins for BTN[1..5] */
    gpio_button_config();

    /* Configure GPIO pins: PA2 PA3 */
    GPIO_InitStruct.Pin = GPIO_PIN_2 | GPIO_PIN_3;
    GPIO_InitStruct.Mode = GPIO_MODE_ANALOG;
    GPIO_InitStruct.Pull = GPIO_NOPULL;
    HAL_GPIO_Init(GPIOA, &GPIO_InitStruct);

    /* Configure GPIO pins: DISP_CS_Pin DISP_DC_Pin */
    GPIO_InitStruct.Pin = DISP_CS_Pin | DISP_DC_Pin;
    GPIO_InitStruct.Mode = GPIO_MODE_OUTPUT_PP;
    GPIO_InitStruct.Pull = GPIO_NOPULL;
    GPIO_InitStruct.Speed = GPIO_SPEED_FREQ_LOW;
    HAL_GPIO_Init(GPIOA, &GPIO_InitStruct);

    /* Configure GPIO pin: DISP_RES_Pin */
    GPIO_InitStruct.Pin = DISP_RES_Pin;
    GPIO_InitStruct.Mode = GPIO_MODE_OUTPUT_PP;
    GPIO_InitStruct.Pull = GPIO_NOPULL;
    GPIO_InitStruct.Speed = GPIO_SPEED_FREQ_LOW;
    HAL_GPIO_Init(DISP_RES_GPIO_Port, &GPIO_InitStruct);

    /* Configure unused GPIO pins: PB1 */
    GPIO_InitStruct.Pin = GPIO_PIN_1;
    GPIO_InitStruct.Mode = GPIO_MODE_ANALOG;
    GPIO_InitStruct.Pull = GPIO_NOPULL;
    HAL_GPIO_Init(GPIOB, &GPIO_InitStruct);

    /* Configure GPIO pin: SENSOR_INT_Pin */
    GPIO_InitStruct.Pin = SENSOR_INT_Pin;
    GPIO_InitStruct.Mode = GPIO_MODE_IT_FALLING;
    GPIO_InitStruct.Pull = GPIO_NOPULL;
    HAL_GPIO_Init(SENSOR_INT_GPIO_Port, &GPIO_InitStruct);

    /* Configure GPIO pin: SENSOR_VSYNC_Pin */
    GPIO_InitStruct.Pin = SENSOR_VSYNC_Pin;
    GPIO_InitStruct.Mode = GPIO_MODE_OUTPUT_OD;
    GPIO_InitStruct.Pull = GPIO_NOPULL;
    HAL_GPIO_Init(SENSOR_VSYNC_GPIO_Port, &GPIO_InitStruct);

    /* EXTI interrupt init */
    HAL_NVIC_SetPriority(EXTI0_1_IRQn, 3, 0);
    HAL_NVIC_EnableIRQ(EXTI0_1_IRQn);
    HAL_NVIC_SetPriority(EXTI4_15_IRQn, 3, 0);
    HAL_NVIC_EnableIRQ(EXTI4_15_IRQn);
}

void i2c1_init(void)
{
    hi2c1.Instance = I2C1;

    /*
     * CubeMX calculated value for the following configuration:
     * - I2C Frequency: 400kHz
     * - Rise Time: 250ns
     * - Fall Time: 100ns
     * - Coefficient of Digital Filter: 0
     * - Analog Filter: Enabled
     */
    hi2c1.Init.Timing = 0x00B0122A;

    hi2c1.Init.OwnAddress1 = 0;
    hi2c1.Init.AddressingMode = I2C_ADDRESSINGMODE_7BIT;
    hi2c1.Init.DualAddressMode = I2C_DUALADDRESS_DISABLE;
    hi2c1.Init.OwnAddress2 = 0;
    hi2c1.Init.OwnAddress2Masks = I2C_OA2_NOMASK;
    hi2c1.Init.GeneralCallMode = I2C_GENERALCALL_DISABLE;
    hi2c1.Init.NoStretchMode = I2C_NOSTRETCH_DISABLE;

    if (HAL_I2C_Init(&hi2c1) != HAL_OK) {
        error_handler();
    }

    /* Configure analog filter */
    if (HAL_I2CEx_ConfigAnalogFilter(&hi2c1, I2C_ANALOGFILTER_ENABLE) != HAL_OK) {
        error_handler();
    }

    /* Configure digital filter */
    if (HAL_I2CEx_ConfigDigitalFilter(&hi2c1, 0) != HAL_OK) {
        error_handler();
    }
}

void tim2_init(void)
{
    /*
     * Default PWM frequency for LED drivers: 651Hz
     *
     * This frequency is a trade-off between having a stable measured LED
     * brightness, and maintaining a 1:1 relationship between duty cycle
     * and brightness when plotted on a logarithmic scale.
     *
     * Frequencies in the 400-1000Hz range do fairly well up to an equivalent
     * of 2.00D, then start to deviate significantly.
     * With a frequency of around 80Hz it is possible to get an equivalent of
     * 3.00D before deviation, but with compromises on stability and
     * measurement timing.
     */
    TIM_ClockConfigTypeDef sClockSourceConfig = {0};
    TIM_MasterConfigTypeDef sMasterConfig = {0};
    TIM_OC_InitTypeDef sConfigOC = {0};

    htim2.Instance = TIM2;
    htim2.Init.Prescaler = 2;
    htim2.Init.CounterMode = TIM_COUNTERMODE_UP;
    htim2.Init.Period = 16383;
    htim2.Init.ClockDivision = TIM_CLOCKDIVISION_DIV1;
    htim2.Init.AutoReloadPreload = TIM_AUTORELOAD_PRELOAD_DISABLE;
    if (HAL_TIM_Base_Init(&htim2) != HAL_OK) {
        error_handler();
    }

    sClockSourceConfig.ClockSource = TIM_CLOCKSOURCE_INTERNAL;
    if (HAL_TIM_ConfigClockSource(&htim2, &sClockSourceConfig) != HAL_OK) {
        error_handler();
    }

    if (HAL_TIM_PWM_Init(&htim2) != HAL_OK) {
        error_handler();
    }

    sMasterConfig.MasterOutputTrigger = TIM_TRGO_RESET;
    sMasterConfig.MasterSlaveMode = TIM_MASTERSLAVEMODE_DISABLE;
    if (HAL_TIMEx_MasterConfigSynchronization(&htim2, &sMasterConfig) != HAL_OK) {
        error_handler();
    }

    sConfigOC.OCMode = TIM_OCMODE_PWM1;
    sConfigOC.Pulse = 0;
    sConfigOC.OCPolarity = TIM_OCPOLARITY_HIGH;
    sConfigOC.OCFastMode = TIM_OCFAST_DISABLE;
    if (HAL_TIM_PWM_ConfigChannel(&htim2, &sConfigOC, TIM_CHANNEL_1) != HAL_OK) {
        error_handler();
    }
    if (HAL_TIM_PWM_ConfigChannel(&htim2, &sConfigOC, TIM_CHANNEL_2) != HAL_OK) {
        error_handler();
    }
    if (HAL_TIM_PWM_ConfigChannel(&htim2, &sConfigOC, TIM_CHANNEL_3) != HAL_OK) {
        error_handler();
    }

    HAL_TIM_MspPostInit(&htim2);
}

void spi1_init(void)
{
    hspi1.Instance = SPI1;
    hspi1.Init.Mode = SPI_MODE_MASTER;
    hspi1.Init.Direction = SPI_DIRECTION_2LINES;
    hspi1.Init.DataSize = SPI_DATASIZE_8BIT;
    hspi1.Init.CLKPolarity = SPI_POLARITY_LOW;
    hspi1.Init.CLKPhase = SPI_PHASE_1EDGE;
    hspi1.Init.NSS = SPI_NSS_SOFT;
    hspi1.Init.BaudRatePrescaler = SPI_BAUDRATEPRESCALER_2;
    hspi1.Init.FirstBit = SPI_FIRSTBIT_MSB;
    hspi1.Init.TIMode = SPI_TIMODE_DISABLE;
    hspi1.Init.CRCCalculation = SPI_CRCCALCULATION_DISABLE;
    hspi1.Init.CRCPolynomial = 7;
    if (HAL_SPI_Init(&hspi1) != HAL_OK) {
        error_handler();
    }
}

void crc_init(void)
{
    hcrc.Instance = CRC;
    hcrc.Init.DefaultPolynomialUse = DEFAULT_POLYNOMIAL_ENABLE;
    hcrc.Init.DefaultInitValueUse = DEFAULT_INIT_VALUE_ENABLE;
    hcrc.Init.InputDataInversionMode = CRC_INPUTDATA_INVERSION_NONE;
    hcrc.Init.OutputDataInversionMode = CRC_OUTPUTDATA_INVERSION_DISABLE;
    hcrc.InputDataFormat = CRC_INPUTDATA_FORMAT_WORDS;
    if (HAL_CRC_Init(&hcrc) != HAL_OK) {
        error_handler();
    }
}

void dma_init(void)
{
    /* DMA controller clock enable */
    __HAL_RCC_DMA1_CLK_ENABLE();

    /* DMA interrupt init */
    /* DMA1_Channel1_IRQn interrupt configuration */
    HAL_NVIC_SetPriority(DMA1_Channel1_IRQn, 3, 0);
    HAL_NVIC_EnableIRQ(DMA1_Channel1_IRQn);
}

void adc_init(void)
{
    ADC_ChannelConfTypeDef sConfig = {0};

    /*
     * Configure the global features of the ADC
     * (Clock, Resolution, Data Alignment and number of conversions)
     */
    hadc.Instance = ADC1;
    hadc.Init.OversamplingMode = ENABLE;
    hadc.Init.Oversample.Ratio = ADC_OVERSAMPLING_RATIO_16;
    hadc.Init.Oversample.RightBitShift = ADC_RIGHTBITSHIFT_NONE;
    hadc.Init.Oversample.TriggeredMode = ADC_TRIGGEREDMODE_SINGLE_TRIGGER;
    hadc.Init.ClockPrescaler = ADC_CLOCK_ASYNC_DIV1;
    hadc.Init.Resolution = ADC_RESOLUTION_12B;
    hadc.Init.SamplingTime = ADC_SAMPLETIME_160CYCLES_5;
    hadc.Init.ScanConvMode = ADC_SCAN_DIRECTION_FORWARD;
    hadc.Init.DataAlign = ADC_DATAALIGN_RIGHT;
    hadc.Init.ContinuousConvMode = ENABLE;
    hadc.Init.DiscontinuousConvMode = DISABLE;
    hadc.Init.ExternalTrigConvEdge = ADC_EXTERNALTRIGCONVEDGE_NONE;
    hadc.Init.ExternalTrigConv = ADC_SOFTWARE_START;
    hadc.Init.DMAContinuousRequests = ENABLE;
    hadc.Init.EOCSelection = ADC_EOC_SEQ_CONV;
    hadc.Init.Overrun = ADC_OVR_DATA_OVERWRITTEN;
    hadc.Init.LowPowerAutoWait = DISABLE;
    hadc.Init.LowPowerFrequencyMode = DISABLE;
    hadc.Init.LowPowerAutoPowerOff = DISABLE;
    if (HAL_ADC_Init(&hadc) != HAL_OK) {
        error_handler();
    }

    /*
     * Configure for the selected ADC regular channel to be converted.
     */
    sConfig.Channel = ADC_CHANNEL_TEMPSENSOR;
    sConfig.Rank = ADC_RANK_CHANNEL_NUMBER;
    if (HAL_ADC_ConfigChannel(&hadc, &sConfig) != HAL_OK) {
        error_handler();
    }

    /*
     * Configure for the selected ADC regular channel to be converted.
     */
    sConfig.Channel = ADC_CHANNEL_VREFINT;
    if (HAL_ADC_ConfigChannel(&hadc, &sConfig) != HAL_OK) {
        error_handler();
    }

    if (HAL_ADCEx_EnableVREFINT() != HAL_OK) {
        error_handler();
    }
    if (HAL_ADCEx_EnableVREFINTTempSensor() != HAL_OK) {
        error_handler();
    }
}

void usb_init(void)
{
    /* Peripheral clock enable */
    __HAL_RCC_USB_CLK_ENABLE();

    /* Peripheral interrupt init */
    HAL_NVIC_SetPriority(USB_IRQn, 3, 0);
}

void startup_log_messages(void)
{
    const app_descriptor_t *app_descriptor = app_descriptor_get();
    uint32_t hal_ver = HAL_GetHalVersion();
    uint8_t hal_ver_code = ((uint8_t)(hal_ver)) & 0x0F;
    uint16_t *flash_size = (uint16_t*)(FLASHSIZE_BASE);

    log_i("\033[0m");
    log_i("---- %s Startup ----", app_descriptor->project_name);
    log_i("HAL Version: %d.%d.%d%c",
        ((uint8_t)(hal_ver >> 24)) & 0x0F,
        ((uint8_t)(hal_ver >> 16)) & 0x0F,
        ((uint8_t)(hal_ver >> 8)) & 0x0F,
        hal_ver_code > 0 ? (char)hal_ver_code : ' ');
    log_i("FreeRTOS: %s", tskKERNEL_VERSION_NUMBER);
    log_i("Device ID: 0x%lX", HAL_GetDEVID());
    log_i("Revision ID: 0x%lX", HAL_GetREVID());
    log_i("Flash size: %dk", *flash_size);
    log_i("SysClock: %ldMHz", HAL_RCC_GetSysClockFreq() / 1000000);
    log_i("Unique ID: %08lX%08lX%08lX",
        __bswap32(HAL_GetUIDw0()),
        __bswap32(HAL_GetUIDw1()),
        __bswap32(HAL_GetUIDw2()));
    log_i("App version: %s", app_descriptor->version);
    log_i("Build date: %s", app_descriptor->build_date);
    log_i("Build describe: %s", app_descriptor->build_describe);
    log_i("Build checksum: %08lX", __bswap32(app_descriptor->crc32));

    if (startup_bkp0r & RCC_CSR_PINRSTF) {
        log_i("Pin reset");
    }
    if (startup_bkp0r & RCC_CSR_PORRSTF) {
        log_i("Power on reset");
    }
    if (startup_bkp0r & RCC_CSR_SFTRSTF) {
        log_i("Software reset");
    }
    if (startup_bkp0r & RCC_CSR_OBLRSTF) {
        log_i("Options bytes loading reset");
    }
    if (startup_bkp0r & RCC_CSR_IWDGRSTF) {
        log_i("IWDG reset");
    }
    if (startup_bkp0r & RCC_CSR_WWDGRSTF) {
        log_i("WWDG reset");
    }
    if (startup_bkp0r & RCC_CSR_LPWRRSTF) {
        log_i("Low-Power reset");
    }

    log_i("-----------------------");
}

int main(void)
{
    /*
     * Initialize the HAL, which will reset of all peripherals, initialize
     * the Flash interface and the Systick.
     */
    HAL_Init();

    /* Configure the system clock */
    system_clock_config();

    /* Read startup flags set by the bootloader */
    read_startup_flags();

    /* Initialize the watchdog */
    iwdg_init();

#ifdef USE_SEGGER_RTT
    /* Initialize the RTT interface */
    SEGGER_RTT_ConfigUpBuffer(0, NULL, NULL, 0, SEGGER_RTT_MODE_NO_BLOCK_SKIP);
#else
    /* Initialize the debug UART */
    usart1_uart_init();
#endif

    /* Initialize the rest of the configured peripherals */
    gpio_init();
    i2c1_init();
    tim2_init();
    spi1_init();
    crc_init();
    dma_init();
    adc_init();
    usb_init();

    watchdog_refresh();

    /* Initialize the RTC */
    rtc_init();

    /* Initialize the FreeRTOS scheduler */
    osKernelInitialize();

    /*
     * Note: Initialization code from this point forward may call FreeRTOS
     * functions that have a side-effect of disabling all interrupts, including
     * the one necessary for the HAL tick timer to function.
     * Starting the FreeRTOS scheduler at the end of this function should
     * make things return to normal behavior.
     */

    /* Initialize the logger */
    logger_init();

    /* Print the initial startup messages */
    startup_log_messages();

    watchdog_refresh();

    /* Create the main task */
    task_main_init();

    /* Start scheduler */
    log_i("Starting scheduler");
    osKernelStart();
}

void HAL_GPIO_EXTI_Callback(uint16_t GPIO_Pin)
{
    if (GPIO_Pin == SENSOR_INT_Pin) {
        sensor_int_handler();
    } else {
        keypad_int_handler(GPIO_Pin);
    }
}

void HAL_ADC_ConvCpltCallback(ADC_HandleTypeDef *hadc)
{
    UNUSED(hadc);
    adc_completion_callback();
}

void HAL_TIM_PWM_PulseFinishedCallback(TIM_HandleTypeDef *htim)
{
    if (htim->Instance == TIM2) {
        if (htim->Channel == HAL_TIM_ACTIVE_CHANNEL_1) {
            light_int_handler(TIM_CHANNEL_1, TIM_IT_CC1);
        } else if (htim->Channel == HAL_TIM_ACTIVE_CHANNEL_2) {
            light_int_handler(TIM_CHANNEL_2, TIM_IT_CC2);
        } else if (htim->Channel == HAL_TIM_ACTIVE_CHANNEL_3) {
            light_int_handler(TIM_CHANNEL_3, TIM_IT_CC3);
        }
    }
}

/**
  * @brief  Period elapsed callback in non blocking mode
  * @note   This function is called  when TIM6 interrupt took place, inside
  * HAL_TIM_IRQHandler(). It makes a direct call to HAL_IncTick() to increment
  * a global variable "uwTick" used as application time base.
  * @param  htim : TIM handle
  * @retval None
  */
void HAL_TIM_PeriodElapsedCallback(TIM_HandleTypeDef *htim)
{
    if (htim->Instance == TIM6) {
        HAL_IncTick();
    }
}

void HAL_RTCEx_WakeUpTimerEventCallback(RTC_HandleTypeDef *hrtc)
{
    UNUSED(hrtc);
    state_suspend_rtc_wakeup_handler();
}

void error_handler(void)
{
    __disable_irq();
    __ASM volatile("BKPT #01");
    while (1) { }
}

#ifdef USE_FULL_ASSERT
/**
 * @brief  Reports the name of the source file and the source line number
 *         where the assert_param error has occurred.
 * @param  file: pointer to the source file name
 * @param  line: assert_param error line source number
 * @retval None
 */
void assert_failed(uint8_t *file, uint32_t line)
{
    printf("Assert failed: file %s on line %ld", file, line);
}
#endif /* USE_FULL_ASSERT */

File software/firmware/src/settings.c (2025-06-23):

#include "settings.h"

#define LOG_TAG "settings"

#include <printf.h>
#include <string.h>
#include <math.h>
#include <elog.h>

#include "util.h"

extern CRC_HandleTypeDef hcrc;

static HAL_StatusTypeDef settings_read_header(bool *valid);
static HAL_StatusTypeDef settings_write_header();

static bool settings_init_cal_sensor(bool force_clear);
static bool settings_clear_cal_sensor();
static bool settings_init_cal_target(bool force_clear);
static bool settings_clear_cal_target();
static bool settings_init_user_settings(bool force_clear);
static bool settings_clear_user_settings();
static bool settings_init_cal_temp_settings(bool force_clear);
static bool settings_clear_cal_temp_settings();

static void settings_set_cal_gain_defaults(settings_cal_gain_t *cal_gain);
static bool settings_load_cal_gain();
static void settings_set_cal_temperature_defaults(settings_cal_temperature_t *cal_temperature);
static bool settings_load_cal_vis_temperature();
static bool settings_load_cal_uv_temperature();
static void settings_set_cal_reflection_defaults(settings_cal_reflection_t *cal_reflection);
static bool settings_load_cal_vis_reflection();
static void settings_set_cal_transmission_defaults(settings_cal_transmission_t *cal_transmission);
static bool settings_load_cal_vis_transmission();
static bool settings_load_cal_uv_transmission();
static void settings_set_user_usb_key_defaults(settings_user_usb_key_t *usb_key);
static bool settings_load_user_usb_key();
static void settings_set_user_idle_light_defaults(settings_user_idle_light_t *idle_light);
static bool settings_load_user_idle_light();
static void settings_set_user_display_format_defaults(settings_user_display_format_t *display_format);
static bool settings_load_user_display_format();

static HAL_StatusTypeDef settings_read_buffer(uint32_t address, uint8_t *data, size_t data_len);
static HAL_StatusTypeDef settings_write_buffer(uint32_t address, const uint8_t *data, size_t data_len);
static HAL_StatusTypeDef settings_erase_page(uint32_t address, size_t len);
#if 0
static float settings_read_float(uint32_t address);
static HAL_StatusTypeDef settings_write_float(uint32_t address, float val);
#endif
static uint32_t settings_read_uint32(uint32_t address);
static HAL_StatusTypeDef settings_write_uint32(uint32_t address, uint32_t val);

/*
 * Header Page (128b)
 * Mostly unused at the moment, will be populated if any top-level system
 * data needs to be stored. Unlike other pages, it begins with a magic
 * string.
 */
#define PAGE_HEADER        (DATA_EEPROM_BASE + 0x0000UL)
#define PAGE_HEADER_SIZE   (128)
#define HEADER_MAGIC       (PAGE_HEADER + 0U) /* "DENSITOMETER\0" */
#define HEADER_START       (PAGE_HEADER + 16U)
#define HEADER_VERSION     1UL

/*
 * Sensor Calibration Data (128b)
 * This page contains data specific to calibration of the sensor behavior
 * without taking any reference targets into account. It is likely that
 * the data stored here will be considered part of factory calibration,
 * unlikely to be performed by a user.
 */
#define PAGE_CAL_SENSOR             (DATA_EEPROM_BASE + 0x0080UL)
#define PAGE_CAL_SENSOR_SIZE        (128)
#define PAGE_CAL_SENSOR_VERSION     1UL

#define CONFIG_CAL_GAIN             (PAGE_CAL_SENSOR + 4U)
#define CONFIG_CAL_GAIN_SIZE        (44U)

#define CONFIG_CAL_RESERVED         (PAGE_CAL_SENSOR + 48U)
#define CONFIG_CAL_RESERVED_SIZE    (32U)

/*
 * Target Calibration Data (128b)
 * This page contains data specific to calibration against reference targets
 * used to ensure the device is providing the correct readings. It is
 * something end users are expected to update periodically, based on
 * materials that may be included with the device.
 */
#define PAGE_CAL_TARGET                    (DATA_EEPROM_BASE + 0x0100UL)
#define PAGE_CAL_TARGET_SIZE               (128U)
#define PAGE_CAL_TARGET_VERSION            1UL

#define CONFIG_CAL_VIS_REFLECTION          (PAGE_CAL_TARGET + 4U)
#define CONFIG_CAL_VIS_REFLECTION_SIZE     (20U)

#define CONFIG_CAL_VIS_TRANSMISSION        (PAGE_CAL_TARGET + 24U)
#define CONFIG_CAL_VIS_TRANSMISSION_SIZE   (16U)

#define CONFIG_CAL_UV_TRANSMISSION         (PAGE_CAL_TARGET + 40U)
#define CONFIG_CAL_UV_TRANSMISSION_SIZE    (16U)

/*
 * User Settings (128b)
 * This page contains any user settings that the device may need to store.
 */
#define PAGE_USER_SETTINGS         (DATA_EEPROM_BASE + 0x0180UL)
#define PAGE_USER_SETTINGS_SIZE    (128)
#define PAGE_USER_SETTINGS_VERSION 3UL

#define CONFIG_USER_USB_KEY        (PAGE_USER_SETTINGS + 4U)
#define CONFIG_USER_USB_KEY_SIZE   (12U)

#define CONFIG_USER_IDLE_LIGHT      (PAGE_USER_SETTINGS + 16U)
#define CONFIG_USER_IDLE_LIGHT_SIZE (12U)

#define CONFIG_USER_DISPLAY_FORMAT      (PAGE_USER_SETTINGS + 28U)
#define CONFIG_USER_DISPLAY_FORMAT_SIZE (8U)
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

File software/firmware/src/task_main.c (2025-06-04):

#include "task_main.h"

#include "stm32l0xx_hal.h"
#include <cmsis_os.h>
#include <tusb.h>

#define LOG_TAG "task_main"
#include <elog.h>

#include "cdc_handler.h"
#include "settings.h"
#include "keypad.h"
#include "display.h"
#include "light.h"
#include "task_usbd.h"
#include "task_sensor.h"
#include "adc_handler.h"
#include "state_controller.h"

extern SPI_HandleTypeDef hspi1;
extern TIM_HandleTypeDef htim2;

extern void system_clock_config(void);

static void task_main_run(void *argument);

typedef struct {
    const osThreadFunc_t task_func;
    const osThreadAttr_t task_attrs;
    osThreadId_t task_handle;
} task_params_t;

static osSemaphoreId_t task_start_semaphore = NULL;
static const osSemaphoreAttr_t task_start_semaphore_attributes = {
    .name = "task_start_semaphore"
};

#define TASK_MAIN_STACK_SIZE (2048U)
#define TASK_USBD_STACK_SIZE (1024U)
#define TASK_CDC_STACK_SIZE (2048U)

#ifdef KEYPAD_DEBUG
#define TASK_KEYPAD_STACK_SIZE (768U)
#else
#define TASK_KEYPAD_STACK_SIZE (256U)
#endif

#define TASK_SENSOR_STACK_SIZE (1024U)

static task_params_t task_list[] = {
    {
        .task_func = task_main_run,
        .task_attrs = {
            .name = "main",
            .stack_size = TASK_MAIN_STACK_SIZE,
            .priority = osPriorityNormal
        }
    },
    {
        .task_func = task_usbd_run,
        .task_attrs = {
            .name = "usbd",
            .stack_size = TASK_USBD_STACK_SIZE,
            .priority = osPriorityNormal2 // example uses max-1
        }
    },
    {
        .task_func = task_cdc_run,
        .task_attrs = {
            .name = "cdc",
            .stack_size = TASK_CDC_STACK_SIZE,
            .priority = osPriorityNormal1 // example uses max-2
        }
    },
    {
        .task_func = task_keypad_run,
        .task_attrs = {
            .name = "keypad",
            .stack_size = TASK_KEYPAD_STACK_SIZE,
            .priority = osPriorityNormal
        }
    },
    {
        .task_func = task_sensor_run,
        .task_attrs = {
            .name = "sensor",
            .stack_size = TASK_SENSOR_STACK_SIZE,
            .priority = osPriorityNormal
        }
    }
};

static bool main_task_running = false;

osStatus_t task_main_init()
{
    /* Create the semaphore used to synchronize task startup */
    task_start_semaphore = osSemaphoreNew(1, 0, &task_start_semaphore_attributes);
    if (!task_start_semaphore) {
        log_e("task_start_semaphore create error");
        return osErrorNoMemory;
    }

    /* Create the main task */
    task_list[0].task_handle = osThreadNew(task_list[0].task_func, NULL, &task_list[0].task_attrs);
    if (!task_list[0].task_handle) {
        log_e("main_task create error");
        return osErrorNoMemory;
    }
    return osOK;
}

bool task_main_is_running()
{
    return main_task_running;
}

void task_main_run(void *argument)
{
    const uint8_t task_count = sizeof(task_list) / sizeof(task_params_t);

    log_d("main_task start");

    /* Initialize the display */
    display_init(&hspi1);
    display_clear();

    /* Initialize the light source */
    light_init(&htim2, TIM_CHANNEL_2, TIM_CHANNEL_1, TIM_CHANNEL_3);
    osDelay(1);

    /* Load system settings */
    settings_init();

    /* Initialize the ADC handler */
    adc_handler_init();

    /* Initialize the state controller */
    state_controller_init();

    /* Loop through the remaining tasks and create them */
    for (uint8_t i = 1; i < task_count; i++) {
        /* Create the next task */
        task_list[i].task_handle = osThreadNew(task_list[i].task_func, task_start_semaphore, &task_list[i].task_attrs);
        if (!task_list[i].task_handle) {
            log_e("%s create error", task_list[i].task_attrs.name);
            continue;
        }

        /* Wait for the semaphore set once the task initializes */
        if (osSemaphoreAcquire(task_start_semaphore, portMAX_DELAY) != osOK) {
            log_e("Unable to acquire task_start_semaphore");
            return;
        }
    }

    main_task_running = true;

    /* Run the infinite main loop */
    log_i("Starting controller loop");
    state_controller_loop();
}

osStatus_t task_main_force_state(state_identifier_t next_state)
{
    if (next_state >= STATE_MAX) { return osErrorParameter; }

    osStatus_t result = osOK;
    keypad_event_t key_event = {
        .key = KEYPAD_FORCE_TIMEOUT,
        .pressed = true
    };

    do {
        /* Clear any pending keypad events */
        result = keypad_clear_events();
        if (result != osOK) { break; }

        /* Inject a key event to make menu key handlers hit timeouts */
        result = keypad_inject_event(&key_event);

        /* Clear any pending task notifications */
        if (xTaskNotifyStateClear(task_list[0].task_handle) != osOK) {
            result = osError;
            break;
        }

        /* Set the task notification for the state change */
        result = osThreadFlagsSet(task_list[0].task_handle, next_state | 0x40000000);
        if (result != osOK) { break; }
    } while (0);

    return result;
}

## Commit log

2023-09-19 Merge hardware from spectrodensitometer project and rename
    The spectrodensitometer R&D project is going to be used as the hardware
    baseline, rather than the original DPD-100, because it has various
    changes that will be useful to this project. Those changes include
    different LEDs, different LED drivers, a temperature sensor, and a 1.8V
    capable LDO.
    [main-board.kicad_pcb, main-board.kicad_sch, trans-led-board.kicad_pcb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]
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2023-09-20 Designed updated transmission LED board with two UV LEDs
    [trans-led-board.kicad_pcb, trans-led-board.kicad_sch]
2023-09-20 Update schematic for UV/VIS requirements
    Switch the light sensor to the TSL2585
    Change the reflection LEDs to the 3000K version
    Add an additional LED driver for the transmission board
    Fix the TVS diodes
    [main-board.kicad_sch]
2023-09-20 Fix misnamed footprint
    [main-board.kicad_sch]
2023-09-20 Finished first pass at layout for new design changes
    [main-board.kicad_pcb, main-board.kicad_sch]
2023-09-21 Clean up transmission board footprints
    Added special narrow footprints for the transmission LEDs, and moved
    them a little bit closer together.
    [trans-led-board.kicad_pcb, trans-led-board.kicad_sch]
2023-09-21 Clean up thermal zones around LED footprints
    [main-board.kicad_pcb, main-board.kicad_sch, trans-led-board.kicad_pcb]
2023-09-21 Enclosure updates
    [dens-base-cover.3mf, dens-base-cover.stl, dens-base.3mf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]
2023-09-21 Prepare boards for first prototype
    Added dates
    Tweaked main board trace/via spacing
    [main-board.kicad_pcb, main-board.kicad_sch, trans-led-board.kicad_pcb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]
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2023-10-06 Initial reworking of sensor task for TSL2585
    Added code to configure and capture readings from the new sensor.
    Updated the diagnostic function to show data from the new sensor.
    Renamed a lot of the old functions and types to avoid having to
    break/rewrite most of the measurement code just yet.
    Right now this is a partial update, and focus will be on the diagnostic
    code paths until more higher level logic can be rewritten around the new
    sensor.
    [cdc_handler.c, sensor.h, task_sensor.c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]
2023-10-06 Added CDC response for sensor temp, and fixed diag gain range
    [cdc_handler.c]
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2023-10-06 Light control bug fix
    [main.c, task_sensor.c]
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2023-10-08 Add 1-layer variant of transmission LED board
    This is for testing with an Aluminum PCB. It does require a slight
    change to the cable pinout to handle routing, so that'll be kludged with
    a patch cable for now and fixed with a real change on the main board
    later... if this approach is taken.
    [trans-led-al-board.kicad_pcb, trans-led-al-board.kicad_sch]
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2023-10-19 Reworking gain calibration process (WIP)
    Rewrote the gain-cal LED brightness finder
    Not sure yet whether to use saturation-1 or 80% of saturation, or
    something that tracks values and attempts to find 80% of max reading.
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2023-11-06 Remove old FR4 transmission board
    Planning to make the Al version into the only version
    [trans-led-board.kicad_pcb, trans-led-board.kicad_sch]
2023-11-06 Renamed all Al board files back to the base name
    [trans-led-board.kicad_pcb, trans-led-board.kicad_sch]
2023-11-06 Updated notes and metadata
    [trans-led-board.kicad_pcb, trans-led-board.kicad_sch]
2023-11-06 Schematic updated to include both LEDs and drivers
    There will likely be a lot of back-and-forth updates between the PCB and
    schematic during routing.
    [trans-led-board.kicad_sch]
2023-11-06 Updated transmission LED board now fully routed
    Still a lot of cleanup and organization work necessary
    [trans-led-board.kicad_pcb, trans-led-board.kicad_sch]
2023-11-06 Transmission LED board rounding cleaned up
    [trans-led-board.kicad_pcb, trans-led-board.kicad_sch]
2023-11-07 Update main board for new transmission board interface
    Removed the two transmission LED drivers from the main board, and routed
    straight to the connecter per the new pinout.
    Added a 10K pull-down to deal with the bootloader pin behavior issue.
    Changed the reflection driver to the MIC4812, for part commonality and
    slightly better thermals.
    [main-board.kicad_pcb, main-board.kicad_sch]
2023-11-17 Initial CMake support for the main firmware and bootloader
    This also includes various IDE-specific files for CLion
    One important gotcha that was discovered, is that the order of the
    linker arguments actually matters. More specifically, the arguments need
    to be passed after the object files to avoid a lot of linker errors that
    crop up. This is covered more in this thread:
    https://community.arm.com/support-forums/f/compilers-and-libraries-forum/54147/gcc-12-2-libc_nano-exporting-retargetable-locking-functions-and-data
2023-11-27 Prepare Rev B for the fab
    [main-board.kicad_pcb, main-board.kicad_sch, trans-led-board.kicad_pcb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]
2023-12-15 Minor fixes and improvements to capturing sensor readings
    Changed the way we handle the FreeRTOS scheduler when reading sensor
    data to avoid unnecessary delays from task switching.
    Added a workaround to an issue where, after a gain change, data would
    continue to be returned before the gain change had fully taken effect.
    This was breaking gain calibration, sometimes.
    This bug still needs to be fixed for real, but the workaround added to
    the gain calibration code is good enough for the time being.
    [task_sensor.c]
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2024-01-02 Fix temperature reading for negative values
    [mcp9808.c]
2024-02-03 Update CAD model files
    [dens-base-cover.3mf, dens-base-cover.stl, dens-base.3mf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]
2024-02-21 Model updates
    [dens-base-cover.3mf, dens-base-cover.stl, dens-base.3mf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]
2024-02-28 First pass updating to KiCad v8
    Still have some schematic symbol and footprint changes to incorporate
    Still need to update custom footprints to new style
    [main-board.kicad_pcb, main-board.kicad_sch, trans-led-board.kicad_pcb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]
2024-02-28 Update symbols changed in library
    [main-board.kicad_pcb, main-board.kicad_sch]
2024-03-02 Mounting holes shouldn't be in the BOM
    [trans-led-board.kicad_sch]
2024-03-02 Various footprint style updates
    [main-board.kicad_pcb, trans-led-board.kicad_pcb]
2024-09-04 Update main board to match common conventions from current projects
    Changed all single-line TVS diodes to the ESD321
    Changed ferrite beads to the new common part.
    Added a 10nF filter capacitor to VBus.
    Made all 10nF filter capacitors now 0603 sized.
    Changed all vias to new common sizes.
    Changed zone clearance settings to new common values.
    [main-board.kicad_pcb, main-board.kicad_sch]
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2024-09-09 Split schematic into multiple files
    [main-board-buttons.kicad_sch, main-board-sensor.kicad_sch, main-board.kicad_pcb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]
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2024-09-09 Add CAD model for ECS crystal oscillator
    Model is incorrectly named from the source. Scaling corrections applied
    in the KiCad footprint to avoid needing to make a new model. This model
    will be replaced if the source ever fixes what they're sharing.
2024-09-09 Add footprint for ECS crystal oscillator
2024-09-10 Replace CAD model with one fixed by upstream
2024-09-10 Update footprint for fixed model
2024-09-10 Fix footprint silkscreen elements
2024-09-10 Implement VSYNC reference signal
    Adds a 32.768kHz oscillator and a binary counter to divide it, providing
    a stable 128Hz signal routed to the sensor's VSYNC pin.
    [main-board-sensor.kicad_sch, main-board.kicad_pcb, main-board.kicad_sch]
2024-09-10 Fix various solder paste and silkscreen issues
    [main-board.kicad_pcb]
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2024-09-24 Final tweaks for Rev C manufacture
    [main-board-buttons.kicad_sch, main-board-sensor.kicad_sch, main-board.kicad_pcb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]
2024-10-24 Fixup for CubeMX files
    [uvdensitometer.ioc]
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2024-10-24 Fix net name for reflection LEDs
    This should match the identifer used in the firmware, for consistency
    [main-board-sensor.kicad_sch, main-board.kicad_pcb, main-board.kicad_sch]
2024-10-24 Update ESD321 symbols and footprints
    Correct the library symbols and footprints used for the ESD321DYAR so
    that the reversed pin 1 indiciation of these components still gets
    assembled correctly.
    Keeping the existing diode footprint with its marking, and adding a
    supplemental dot to indicate how pin 1 differs from what this footprint
    otherwise suggests.
    This should make all the data correct, though an extra note in assembly
    guidance will be necessary just in case.
    Fix #1
    [main-board-buttons.kicad_sch, main-board-sensor.kicad_sch, main-board.kicad_pcb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]
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2024-10-27 Change LED configuration on transmission board
    Put four visible light LEDs on the outer ring, configured for 100mA each
    Put a single higher-power UV LED in the center, configured for 400mA
    Route things to maintain the same connector pin-out
    Clean up board corners
    Testing has shown that four corner LEDs only provide about 25% more
    usable light than a single center LED, when all LEDs are run at the same
    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
    [trans-led-board.kicad_pcb, trans-led-board.kicad_sch]
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2024-10-28 CMake integration improvements
    Rework the way CMake is used in the project such that all the external
    bits have their own CMake configurations and are linked as intermediary
    libraries.
    This provides a more structured build process, and lets CMake handle
    some of the dependency management. It is also similar to how the
    Printalyzer Timer project is now built.
    This will also make it easier to integrate libraries that provide their
    own CMake configurations.
2024-10-28 Add oscillator calibration to sensor startup
    The Rev C hardware now has a 128Hz reference signal routed to the
    TSL2585 sensor's VSYNC pin. This change adds the code to use that signal
    to perform sensor oscillator calibration on sensor startup. This
    routine is fairly quick, and will run every time the sensor is started
    to take a measurement.
    The one downside of this change is that the sensor will now fail to
    start if the signal is absent, so the related code must be commented out
    prior to testing on Rev B hardware. This could be worked around with
    better error handling in the future, or just left in if we assume this
    feature will remain going forward.
    [cdc_handler.c, task_sensor.c, tsl2585.c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]
2024-10-29 Rework sensor read loop
2024-10-29 Update command interface and documentation
    This should round out the necessary changes to the USB-CDC command
    interface for controlling features specific to the UV-VIS device, from a
    configuration perspective.
    Changes to how density readings are reported are still TBD, and should
    follow shortly.
    Furthermore, the protocol documentation has been updated to reflect all
    existing and new changes.
    Eventually a merged protocol document should be written, explicitly
    indicating differences between the various models, and perhaps included
    as part of the desktop application's documentation.
    [cdc_handler.c]
2024-11-01 Reduce measurement cycle time
    This reduces total cycle time of a density measurement from ~900ms down
    to ~700ms. It does this with a couple of small changes.
    - Reduce AGC sample count
    - Reduce ALS sample count during AGC period to an absolute minimum
    - Slightly increase ALS sample count during AGC disable process to
    prevent FIFO overflow
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2024-11-04 Remove measurement light calibration settings
    Ideally all density measurements should be taken with the measurement
    light at its maximum power with no PWM. However, due to manufacturing
    variations, this ended up violating some assumptions of the gain
    selection process on the DPD-100. As such, a calibrated max light value
    was put in as a last-minute fix to avoid having to make any rushed
    changes to such a critical code path.
    With the newer UV/VIS device, gain selection is a completely different
    process and this issue does not exist. It is therefore always safe to
    just use the maximum brightness for measurement. So there is no point in
    leaving in any of the old code that was there to handle t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
    [cdc_handler.c, sensor.h, settings.c]
2024-11-11 Fix docs and command type checks for diagnostic read
    Docs didn't cover the SMUX argument, and the commend implementation
    didn't enforce the command type.
    [cdc_handler.c]
2024-11-11 Expand remote reading commands
    Added a command to do a full remote measurement cycle, with all the same
    gain detection logic as a user-triggered measurement. This is to support
    device characterization experiments where we'd rather not hard-code
    sensor settings. Only issue is that this returns basic counts, and thus
    won't give useful data unless gain calibration has already been
    performed.
    Added arguments to both the remote read and remote measure commands to
    allow for explicitly setting the light brightness. Normally these will
    be set to the max value, but there are diagnostic cases where it may be
    desired to change them.
    [cdc_handler.c, sensor.h]
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2024-11-18 Implement temperature correction of density measurements
    Moved all access to the temperature sensor into the sensor task, to deal
    with potential I2C peripheral synchronization issues.
    Capture temperature readings right before sensor readings.
    Perform temperature correction of all normal densitometer readings,
    right before slope correction.
    Dedicated diagnostly measurements are not corrected, since those are
    intended to be substantially processed externally.
    [cdc_handler.c, sensor.h, task_main.c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]
2024-11-22 Remove crystal reference and reroute VSYNC pin
    In testing with Rev C hardware, it was determined that using the VSYNC
    pin to calibrate the TSL2585's internal oscillator can actually
    introduce more instability in sensor timing than would otherwise exist.
    Furthermore, the most likely factor affecting oscillator stability is
    temperature, which we're already planning to correct for.
    Thus these extra components should be removed from the design.
    For the sake of future-proofing, the VSYNC pin is now rounded directly
    to the MCU (though a pull-up resistor), in case someday it is decided to
    use this as a measurement trigger. It is also likely this pin will never
    be used, but it doesn't really hurt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
    [main-board-buttons.kicad_sch, main-board-sensor.kicad_sch, main-board.kicad_pcb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]
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2024-12-02 Change pin 1 marker on diode to avoid getting in the way of traces
2024-12-03 Final routing and silkscreen tweaks
    Fixed some trace sizing cruft
    Swapped TVS diode footprints for better pin 1 clarity
    [main-board.kicad_pcb]
2024-12-03 Update panelization configuration for boards
    Tweaked sizes to get tooling holes on a 10mm grid
    Added rail tabs to the transmission boards due to corner features
    Removed web generation because pcbdraw is broken
2024-12-03 Final fixups for gerber export
    [main-board.kicad_pcb]
2024-12-05 Update various project CAD models
    [dens-base-cover.3mf, dens-base-cover.stl, dens-base.3mf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]
2024-12-05 Remove sensor oscillator calibration code
    It has been decided to remove this feature from the hardware, so it
    should also be removed from the firmware.
    Calibration the sensor's oscillator to an external reference sounds nice
    in theory, but there's enough error in the process that it actually
    makes the sensor timing less stable if done regularly.
    Going forward, if the sensor's VSYNC pin is used for anything at all, it
    should only be used to trigger readings. And even that is not too likely
    due to overhead.
    [cdc_handler.c, task_sensor.c]
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2025-02-03 Clean up gain calibration status reporting
    Removed various bits of unused code around LED target factors and
    measurement brightness.
    Reworked status reporting during gain calibration
    [sensor.h]
2025-02-03 Use temp corrected values for calibration measurement
    Omitting this was a bug
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2025-02-21 Minor changes for a quick order of a copper substrate variant
    If this ends up being the final version of the transmission LED board,
    then it should be merged back into master with notes and cleanup to make
    the changes obvious.
    Right now its just the bare minimum of changes to support JLCPCB's
    copper PCB service, with some aspects being in the manufacturing notes
    and not the KiCad files.
    [trans-led-board.kicad_pcb]
2025-02-21 Update KiCad projects to v9 format
    [main-board-buttons.kicad_sch, main-board-sensor.kicad_sch, main-board.kicad_pcb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]
2025-02-21 Update notes for board construction
    [trans-led-board.kicad_pcb, trans-led-board.kicad_sch]
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2025-03-06 Change LED PWM frequency and update startup code
    With the minimum startup pulse duration now being shorter than a full
    timer cycle, this process gets a bit cleaner.
    [light.c, main.c]
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2025-03-07 Fix last remaining light value constant
    [sensor.h]
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2025-05-02 Add 3D printable models for step wedge alignment jigs
    [jig-cal-t2120-center.3mf, jig-cal-t2120-center.stl, jig-cal-t2120-side.3mf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]
2025-05-16 Gain calibration process rewrite
    The creative approach to gain calibration that was originally
    implemented, did not produce the greatest results when compared to a
    more "correct" manual filter-based calibration.
    Fixing this involved a complete change to how gain calibration is
    performed, with the new approach giving similar results to a
    filter-based calibration.
    The first step was to change the LED PWM frequency during gain
    calibration for better sensor behavior. This means the timer running
    that signal is now configurable, using a high-frequency/low-range
    setting for gain calibration and a low-frequency/high-range setting for
    normal operation.
    The next step was to separate the process o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
    [light.c, main.c]
2025-05-23 Remove slope/linearity calibration features
    Extensive testing with various reference materials has shown that the
    slope calibration features, which were mostly inherited from the
    DPD-100, are probably best avoided going forward.
    The nature of any corrections are highly dependent on exactly which
    reference materials are used, and are thus not a trustworthy calibration
    of general sensor behavior. Furthermore, if corrections are ever
    re-added, they likely would need to be measurement-mode-specific for
    this reason.
    Furthermore, the primary driver for the slope corrections on the DPD-100
    was a low-density error curve that was observed in testing. This was
    also observed on the DPD-105 (this dev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
    [cdc_handler.c, sensor.h, settings.c]
2025-05-27 Minor gain calibration tweaks
    Adding an extra delay to the gain brightness loop.
    Using floor instead of ceiling when calculating measurement brightness.
    Detect saturation during gain measurement.
    This is all intended to reduce the probability of a saturation error
    during the calibration process, and to actually detect and fail if one
    happens.
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2025-06-04 Increase size of CDC handler task stack
    Lately there have been some spurious device resets when controlling it
    through the USB-CDC interface. Further investigating has shown that task
    overflows on the "cdc" task sometimes happen, and the watermark was
    awfully close to the limit.
    To try and solve this, the stack size of that task has been increased.
    [task_main.c]
2025-06-07 Simplify the temperature correction process
    This gets rid of the overly complex and hard-to-explain approach to
    correcting for temperature with multiple independent variables, and
    moves towards a much simpler approach. The new approach uses a simple
    polynomial regression on a single indepdendent variable to correct for the
    relationship between temperature and reading.
    This commit itself updates the USB-CDC configuration protocol, the
    settings data structures, and the correction function, to support this
    change.
    [cdc_handler.c, settings.c]
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2025-08-20 Update to assembly instructions and models
    [diffuser-spacer.3mf, diffuser-spacer.stl, filter-stack-holder.3mf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]
2025-08-21 Fix some material thicknesses
2025-09-11 Add on-device display of temperature cal coefficients
    Added the menu option for this right under the menu option for
    displaying the gain cal values.
    Display format is rather terse, and uses scientific notation. Its mostly
    intended to allow quick sanity checking of device calibration, and not
    really user friendly.
    Fix #3
2025-09-11 Disable the diagnostics menu for normal builds
    The diagnostics menu is useless for normal end user purposes. It is a
    nice to have for quick device testing, but it also makes it possible to
    easily turn on the measurement LEDs at full power. That's probably not
    a good idea, especially with the UV LED.
    Fix #4
2025-09-11 Update calibration result screens to distinguish VIS-vs-UV modes
    This is distinguished on the UI flow going into the calibration screens,
    but was not mentioned at the end. It should be, so the user knows which
    sort of calibration they completed.
    There is no need to mention this in the middle, because all included
    calibration references contain values for both modes.
    Fix #5
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2025-09-24 Fix enclosure base cover model
    Improve alignment tab clearance
    Add internal mounting screw clearance pockets
    Fix #6
